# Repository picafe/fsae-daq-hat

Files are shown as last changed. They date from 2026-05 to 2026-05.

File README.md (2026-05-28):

# FSAE Pi HAT
## What this project is

This project is a revision 2.5 of the Raspberry Pi DAQ (data acquisition) HAT for Western Formula Racing FSAE. It consolidates the features still needed from the failed rev 2 boards into a single HAT: a 24 V → 5 V buck converter to power the Pi, input protection on the car rail, CAN transceiver + controller, static PoE injection control, and RTC with coin cell for the Pi 4B.

## Why I made it

A few months ago, I and another WFR team member tested and diagnosed a cause of catastrophic failure of the rev 2 DAQ HAT using voltage injection and a thermal camera. Although rev 3 was planned, and I am still working on it with help from others, the current failed rev 2 PCBs are still being partially used for their features that still function. This aims to be a quick revision that consolidates some of the features, while being cheap to manufacture. When revision 3 is finished, these boards can act as a backup.

The buck converter is one of the essential parts of the hat. Existing modules cut too many corners to be reliable, especially at 3A peak current. Currently, the buck coverter on the Rev 2 board is blown up. 

Rev 2 also included a boost converter to boost 20V USB-C PD to 24 V for injecting PoE for the base station antenna, and for ease of powering during testing. Since this is at a lower current, I decided to use a modified MT3608 boost converter and a PDC004 USB-C PD trigger on a separate PCB for ease of design and cost.

## Pictures

### 3D

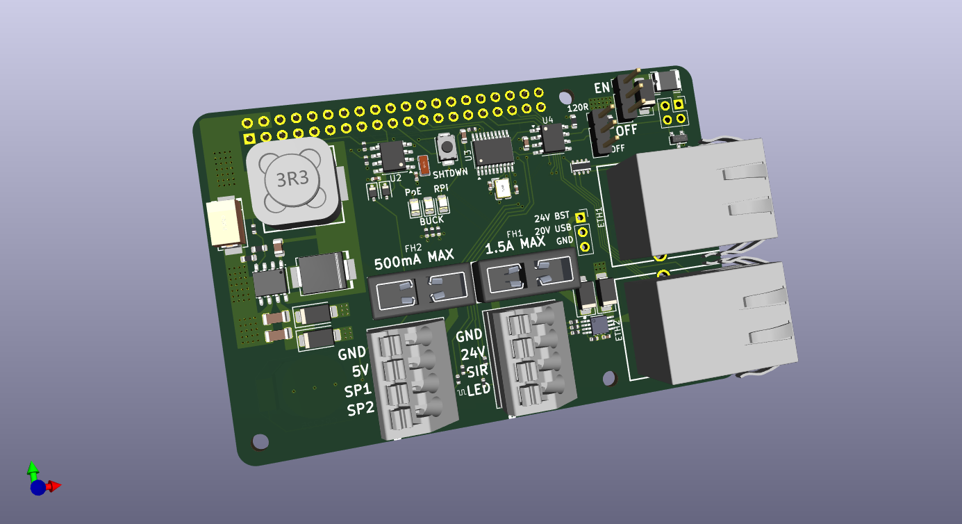
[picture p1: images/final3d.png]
3D view


### Schematic

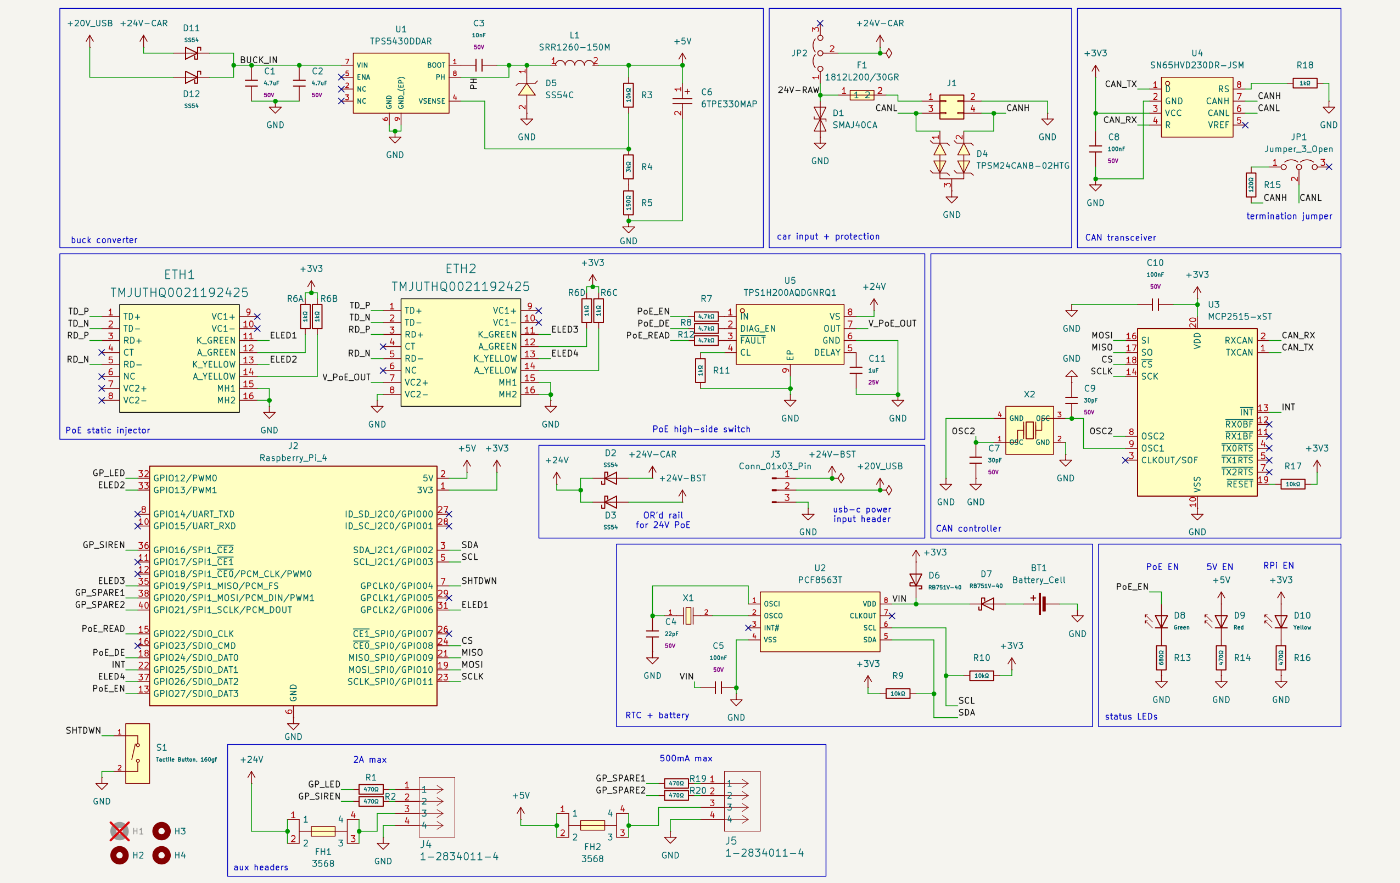
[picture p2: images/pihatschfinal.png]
Final schematic sheet


**[View schematic online (KiCanvas)](https://kicanvas.org/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)**

### PCB (KiCad)

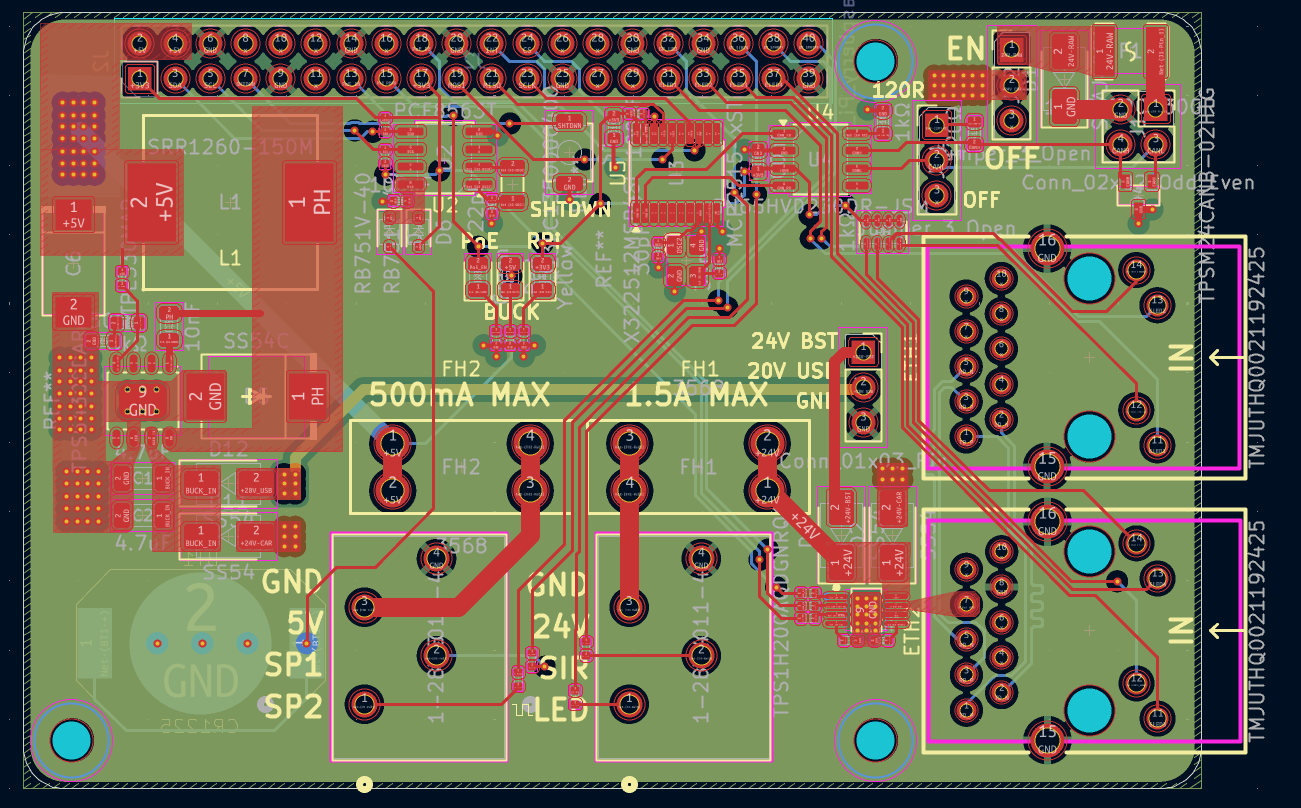
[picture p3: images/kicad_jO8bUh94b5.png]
PCB layout top layer

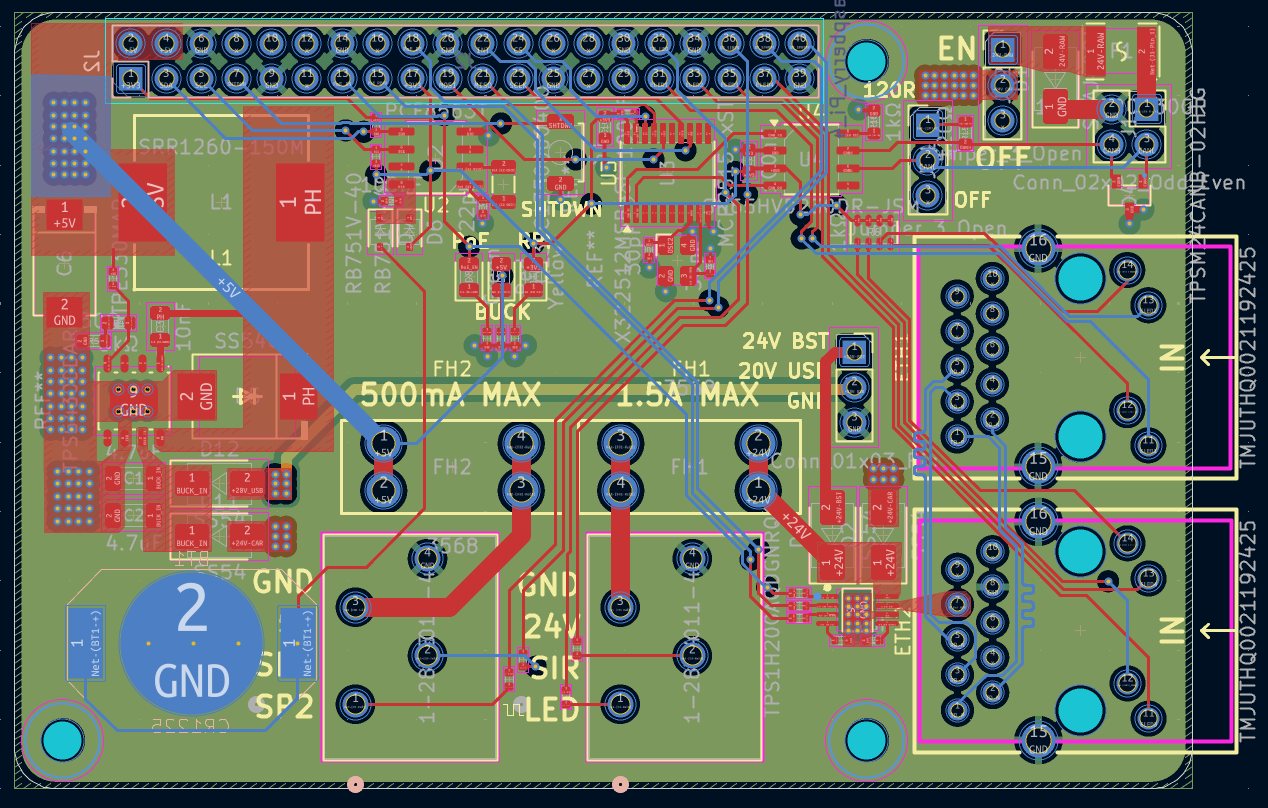
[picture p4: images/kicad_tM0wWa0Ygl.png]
PCB layout bottom layer


**[View PCB online (KiCanvas)](https://kicanvas.org/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)**

### Wiring (off-board)

The 20 V USB-C PD → 24 V boost path is **not** on this HAT. It is implemented on the companion [USB boost/PD module](./fsae-pihat-usbmod/README.md), wired to the **J3** pads on the HAT.

```text
HAT J3 pads (no header installed)
    │  wire
    ▼
Deutsch connector
    │  wire
    ▼
USB-C PD breakout (MT3608 + PDC004)
```
The 2 main power devices source power from different sources using power OR-ing with schottky barrier diodes. 

The buck converter is powered by 24V from the car rail or the 20V USB-C PD (to reduce strain on the boost converter and to keep less ripple on the 5 V rail).
The PoE injector is powered by 24V from the car rail or the 24v boost converter.

A jumper on the **24 V car** input (JP2) can disable the car rail without unplugging the Deutsch connector, to preserve the car battery during bench testing. This MUST be populated to enable the car rail with a high current 0.1" pitch jumper. There is also a CAN termination jumper (JP1) to enable or disable 120Ω termination on the CAN bus.

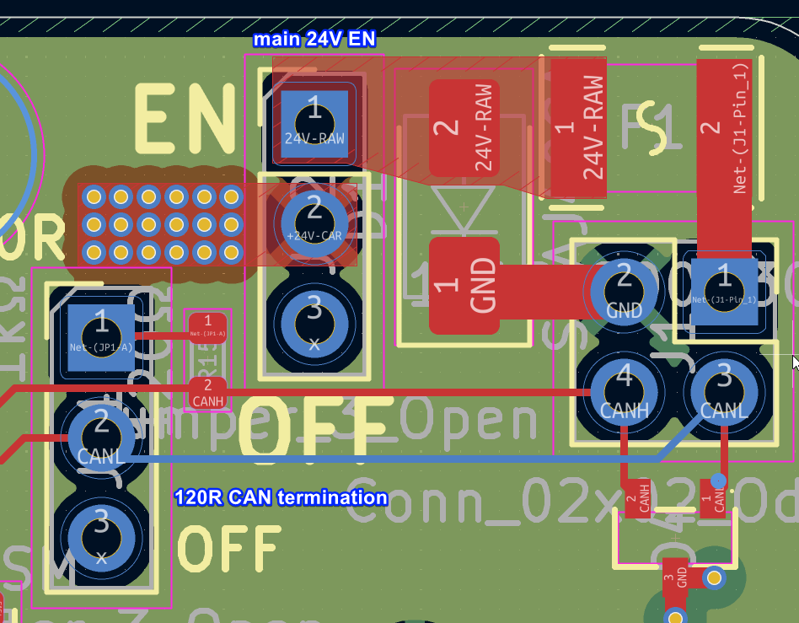
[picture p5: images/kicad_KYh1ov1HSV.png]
Car-rail disable jumper (JP2)


## USB boost / PD module

The MT3608 boost and PDC004 USB-C PD trigger are on a separate PCB. Schematics, layout, images, and BOM for that board are in **[fsae-pihat-usbmod/README.md](./fsae-pihat-usbmod/README.md)**.

## Bill of materials (Pi HAT)

### JLCPCB SMT assembly

| Refs | Qty | Description | LCSC | Unit (USD) | Min | Ext. @ min (USD) |
| --- | ---: | --- | --- | ---: | ---: | ---: |
| C1, C2, C3 | 3 | 4.7 µF ±10% 50 V X7R ceramic, 1206 | [C29823](https://www.lcsc.com/product-detail/C29823.html) | $0.0426 | 10 | $0.43 |
| C10, C9 | 2 | 30 pF ±5% 50 V C0G ceramic, 0402 | [C1570](https://www.lcsc.com/product-detail/C1570.html) | $0.0013 | 100 | $0.13 |
| C11, C12 | 2 | 100 nF ±10% 50 V X7R ceramic, 0603 | [C14663](https://www.lcsc.com/product-detail/C14663.html) | $0.0031 | 100 | $0.31 |
| C4 | 1 | 10 nF ±10% 50 V X7R ceramic, 0805 | [C1710](https://www.lcsc.com/product-detail/C1710.html) | $0.0072 | 50 | $0.36 |
| C5 | 1 | 22 pF ±5% 50 V C0G ceramic, 0402 | [C1555](https://www.lcsc.com/product-detail/C1555.html) | $0.0014 | 100 | $0.14 |
| C6 | 1 | 330 µF ±20% 6.3 V tantalum, 7.3×4.3 mm SMD (6TPE330MAP) | [C79112](https://www.lcsc.com/product-detail/C79112.html) | $0.6851 | 1 | $0.69 |
| C7 | 1 | 100 nF ±10% 50 V X7R ceramic, 0402 | [C307331](https://www.lcsc.com/product-detail/C307331.html) | $0.0047 | 100 | $0.47 |
| C8 | 1 | 1 µF ±10% 25 V X5R ceramic, 0402 | [C52923](https://www.lcsc.com/product-detail/C52923.html) | $0.0040 | 100 | $0.40 |
| D1, D2, D4, D5 | 4 | 40 V 5 A Schottky, SMA (SS54) | [C7420369](https://www.lcsc.com/product-detail/C7420369.html) | $0.0448 | 10 | $0.45 |
| D10 | 1 | Emerald green 525 nm LED, 2.6–3.1 V, 0805 | [C2297](https://www.lcsc.com/product-detail/C2297.html) | $0.0163 | 50 | $0.82 |
| D11 | 1 | Red 630 nm LED, 1.6–2.6 V, 0805 | [C84256](https://www.lcsc.com/product-detail/C84256.html) | $0.0133 | 50 | $0.67 |
| D12 | 1 | Yellow 596 nm LED, 1.8–2.4 V, 0805 | [C2296](https://www.lcsc.com/product-detail/C2296.html) | $0.0122 | 50 | $0.61 |
| D3 | 1 | 40 V 5 A Schottky, SMC (SS54C) | [C18199188](https://www.lcsc.com/product-detail/C18199188.html) | $0.0737 | 10 | $0.74 |
| D6 | 1 | 64.5 V clamp TVS, 6.2 A Ipp, DO-214AC/SMA (SMAJ40CA) | — | — | — | — |
| D7, D9 | 2 | 40 V 30 mA Schottky, SOD-323 (RB751V-40) | [C7502691](https://www.lcsc.com/product-detail/C7502691.html) | $0.0149 | 50 | $0.75 |
| D8 | 1 | 50 V CAN TVS clamp, 5.5 A Ipp, SOT-23 (TPSM24CANB-02HTG) | [C970029](https://www.lcsc.com/product-detail/C970029.html) | $0.0495 | 10 | $0.50 |
| F1 | 1 | Polymeric PTC resettable fuse, 30 V 2 A, 1812 (1812L200/30GR) | [C18198342](https://www.lcsc.com/product-detail/C18198342.html) | $0.0812 | 5 | $0.41 |
| L1 | 1 | 15 µH ±20% shielded inductor, 5 A, 12.5×12.5 mm (SRR1260-150M) | [C2041333](https://www.lcsc.com/product-detail/C2041333.html) | $1.3721 | 1 | $1.37 |
| R1 | 1 | 1 kΩ ±5% resistor network, 0603×4 | [C20197](https://www.lcsc.com/product-detail/C20197.html) | $0.0059 | 50 | $0.30 |
| R10, R11, R12 | 3 | 4.7 kΩ ±1% thick-film, 0402 | [C25900](https://www.lcsc.com/product-detail/C25900.html) | $0.0010 | 100 | $0.10 |
| R13, R14, R19, R21, R4 | 5 | 10 kΩ ±1% thick-film, 0402 | [C25744](https://www.lcsc.com/product-detail/C25744.html) | $0.0013 | 100 | $0.13 |
| R15 | 1 | 680 Ω ±1% thick-film, 0402 | [C25130](https://www.lcsc.com/product-detail/C25130.html) | $0.0011 | 100 | $0.11 |
| R16, R18, R2, R3, R7, R8 | 6 | 470 Ω ±1% thick-film, 0402 | [C25117](https://www.lcsc.com/product-detail/C25117.html) | $0.0008 | 100 | $0.08 |
| R17 | 1 | 120 Ω ±1% thick-film, 0603 (CAN termination) | [C22787](https://www.lcsc.com/product-detail/C22787.html) | $0.0014 | 100 | $0.14 |
| R20 | 1 | 1 kΩ ±1% thick-film, 0603 | [C21190](https://www.lcsc.com/product-detail/C21190.html) | $0.0016 | 100 | $0.16 |
| R5 | 1 | 3 kΩ ±1% thick-film, 0603 | [C4211](https://www.lcsc.com/product-detail/C4211.html) | $0.0014 | 100 | $0.14 |
| R6 | 1 | 150 Ω ±1% thick-film, 0603 | [C22808](https://www.lcsc.com/product-detail/C22808.html) | $0.0018 | 100 | $0.18 |
| R9 | 1 | 1 kΩ ±1% thick-film, 0402 | [C11702](https://www.lcsc.com/product-detail/C11702.html) | $0.0011 | 100 | $0.11 |
| S1 | 1 | Tactile switch SPST, 160 gf, 4×3 mm SMD (TS-1088) | [C720477](https://www.lcsc.com/product-detail/C720477.html) | $0.0538 | 10 | $0.54 |
| U1 | 1 | TPS5430 buck regulator, 3 A, 5.5–36 V in, SOIC-8-EP | [C9864](https://www.lcsc.com/product-detail/C9864.html) | $0.7486 | 1 | $0.75 |
| U2 | 1 | TPS1H200A 2.5 A high-side switch (PoE injector), EMSOP-8-EP | [C2653785](https://www.lcsc.com/product-detail/C2653785.html) | $0.7476 | 1 | $0.75 |
| U3 | 1 | PCF8563T I²C real-time clock, SO-8 | [C7440](https://www.lcsc.com/product-detail/C7440.html) | $0.5834 | 1 | $0.58 |
| U4 | 1 | SN65HVD230 3.3 V CAN transceiver, 5 Mbps, SOP-8 | [C46596299](https://www.lcsc.com/product-detail/C46596299.html) | $0.4853 | 1 | $0.49 |
| U5 | 1 | MCP2515 1 Mbps CAN controller, TSSOP-20 | — | — | — | — |
| X1 | 1 | 32.768 kHz crystal ±20 ppm, 12.5 pF, SMD3215-2P | [C32346](https://www.lcsc.com/product-detail/C32346.html) | $0.1804 | 5 | $0.90 |
| X2 | 1 | 12 MHz crystal ±10 ppm, 20 pF, SMD3225-4P | [C9002](https://www.lcsc.com/product-detail/C9002.html) | $0.0744 | 10 | $0.74 |
| | | **LCSC subtotal @ MOQ** | | | | **$15.45 + 2 unlinked line items** |

### DigiKey (hand assembly)

| Refs | Qty | Description | DigiKey | Unit (CAD) | Ext. (CAD) |
| --- | ---: | --- | --- | ---: | ---: |
| J2 | 1 | 2×20 extended female GPIO header | [1568-16763-ND](https://www.digikey.ca/en/products/detail/sparkfun-electronics/16763/12686348) | $4.70 | $4.70 |
| J4, J5 | 2 | 4-pos 3.5 mm top-entry terminal block | [A123850-ND](https://www.digikey.ca/en/products/detail/te-connectivity-amp-connectors/1-2834011-4/5872966) | $1.57 | $3.14 |
| ETH1, ETH2 | 2 | RJ45 magjack 10/100 + PoE (Taoglas) | [931-TMJUTHQ0021192425-ND](https://www.digikey.ca/en/products/detail/taoglas-limited/TMJUTHQ0021192425/21777733) | $9.04 | $18.08 |
| FH1, FH2 | 2 | Blade fuse holder 30 A 500 V PCB | [36-3568-ND](https://www.digikey.ca/en/products/detail/keystone-electronics/3568/2137306) | $1.69 | $3.38 |
| BT1 | 1 | CR1225 coin-cell holder, 12 mm SMD | [BAT-HLD-012-SMTCT-ND](https://www.digikey.ca/en/products/detail/te-connectivity-linx/BAT-HLD-012-SMT-TR/5361776) | $0.75 | $0.75 |
| — | 1 | CR1225 3 V lithium cell (fits BT1) | *(Amazon, etc.)* | — | — |
| JP1, JP2 | 2 | 1×3 2.54 mm vertical pin header (solder to `JP1` / `JP2` footprints) | *(any 1×3 0.1″ 3A rated header)* | — | — |
| JP1 | 1 | CAN 120 Ω termination shunt | [S9341-ND](https://www.digikey.ca/en/products/detail/sullins-connector-solutions/NPC02SXON-RC/2618266) | $0.075 | $0.08 |
| JP2 | 1 | 24 V car-rail enable shunt | [S9341-ND](https://www.digikey.ca/en/products/detail/sullins-connector-solutions/NPC02SXON-RC/2618266) | $0.075 | $0.08 |
| | | **DigiKey subtotal (per board)** | | | **$30.20** |

**Not populated (DNP):**

| Refs | Footprint on PCB | Notes |
| --- | --- | --- |
| J1 | 2×2 pin socket | Do not install; car input harness wires solder to |
| J3 | 1×3 pin header | Do not install; boost/PD harness wires solder to |

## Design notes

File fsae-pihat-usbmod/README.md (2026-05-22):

# FSAE Pi HAT USB Boost / PD Module

## What this project is

This PCB is the external **20 V USB-C PD → 24 V boost** module used with the [main Pi HAT](../README.md). It pairs a **PDC004 V2** USB-C PD trigger (fixed 20 V) with an **MT3608** boost module to generate 24 V for PoE injection on the base station antenna and for convenient bench power during testing. This is a companion PCB to the main Pi HAT.

## Why I made it

Since the current here would be pretty low, I decided to use a MT3608 and PDC004 PD module (I already have one, and the design seems pretty good; really big power plane on bottom) on a separate PCB instead of putting a boost converter on the HAT.

The MT3608 module also should be able to handle the current required (2 A) for the 24 V PoE injection, which should be around 1 A peak. The IC itself is pretty capable; there often just is not a great component selection or insufficient decoupling/filtering. I remembered [this GreatScott video](https://www.youtube.com/watch?v=6bicunweBAQ) where he added a 2.2 µF 1210 capacitor to the output of the MT3608 to improve output ripple, so I added **C1 (2.2 µF)**.

## Pictures

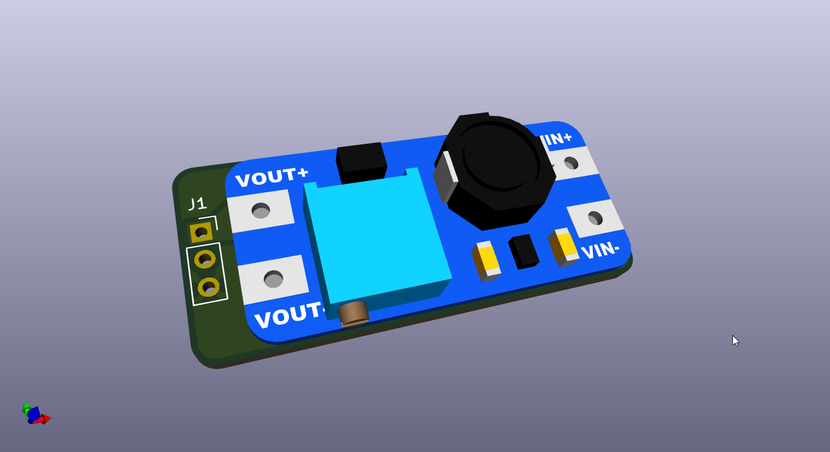
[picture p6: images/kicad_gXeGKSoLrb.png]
3D view top (MT3608)


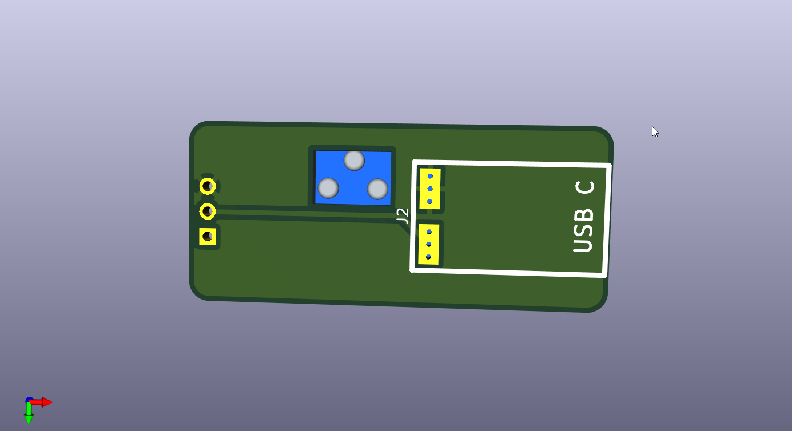
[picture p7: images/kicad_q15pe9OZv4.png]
3D view bottom (PDC004)


### Schematic

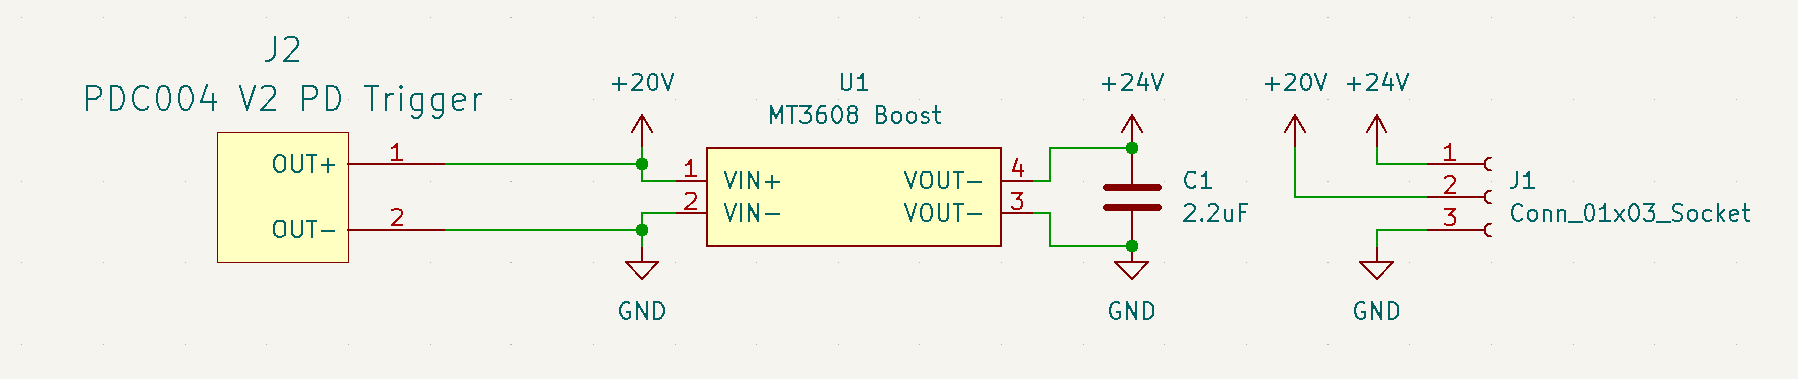
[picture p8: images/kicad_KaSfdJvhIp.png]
Schematic sheet


**[View schematic online (KiCanvas)](https://kicanvas.org/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)**

### PCB

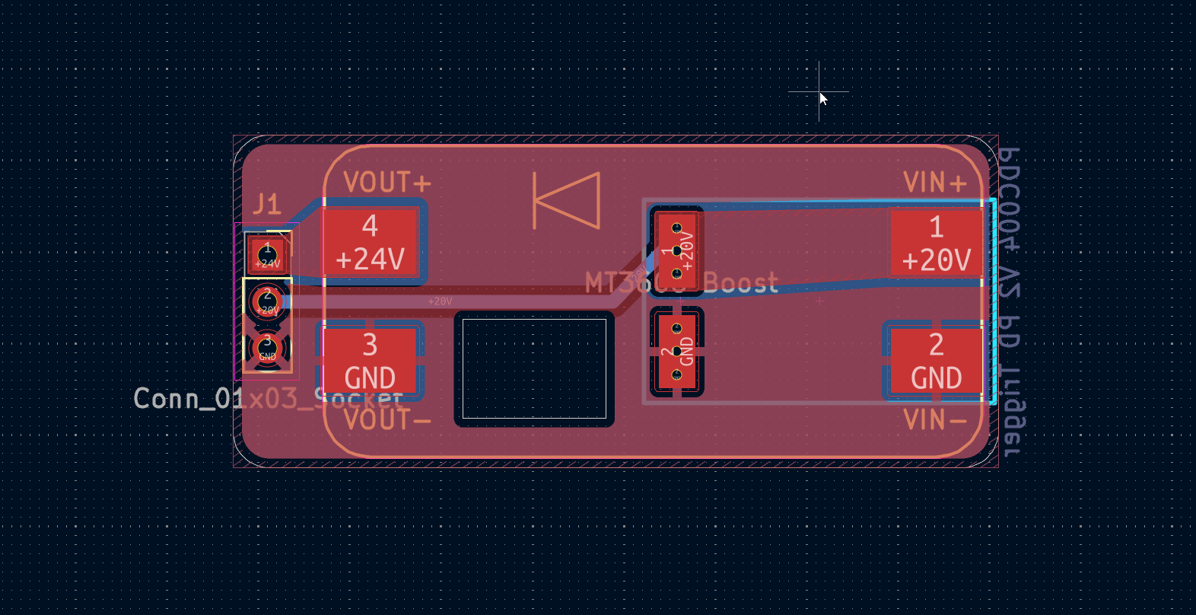
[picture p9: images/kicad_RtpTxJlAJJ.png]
PCB layout top)


**[View PCB online (KiCanvas)](https://kicanvas.org/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)**

### Wiring (off-board)

Connect to the main HAT **J3** and a USB-C PD supply:

```text
USB-C PD supply (20 V negotiated)
    │
    ▼
PDC004 module (J2, bottom of this PCB) ──► +20 V rail
    │
    ▼
MT3608 boost (U1, top of this PCB) ──► +24 V
    │
    ▼
3-pin header J1 ──► wires ──► Deutsch connectors ──► main HAT J3
```

For the PCB, the PD module is surface mount on the bottom and the MT3608 on the top, since both have large pads on both sides with vias.

## Bill of materials

| Designator | Footprint / package | Qty | Value | Notes |
| --- | --- | ---: | --- | --- |
| J1 | PinSocket_1x03_P2.54mm_Vertical | 1 | Conn_01x03_Socket | To main HAT |
| J2 | PDC004 Module | 1 | PDC004 PD Trigger | Fixed 20 V USB-C PD; AliExpress module |
| U1 | MT3608 Module | 1 | MT3608 Boost | AliExpress / generic boost module |
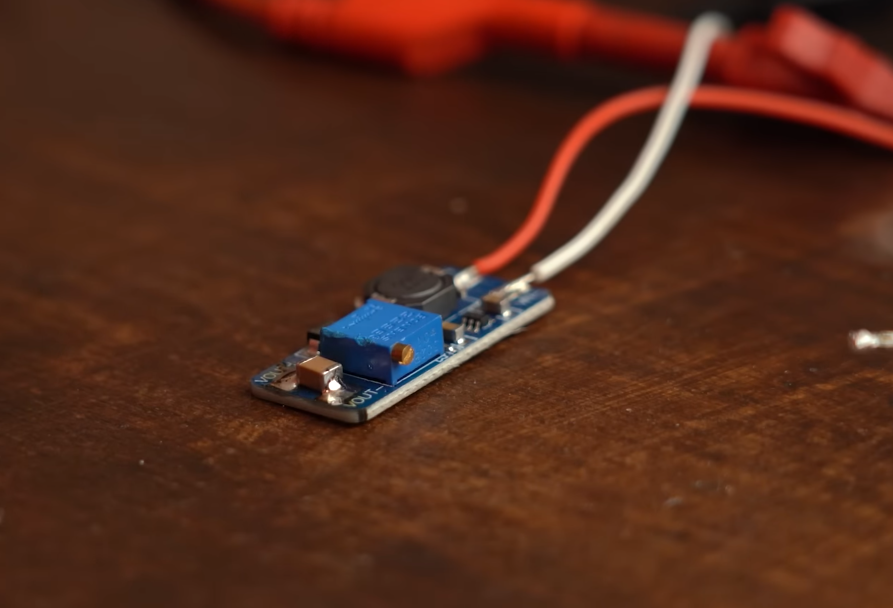
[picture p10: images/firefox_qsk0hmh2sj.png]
soldering example - GreatScott
| C1 | C_1210 (hand solder on module) | 1 | [2.2 µF, 50V X7R 1210 CL32B225KBJNNNE](https://www.digikey.ca/en/products/detail/samsung-electro-mechanics/CL32B225KBJNNNE/3888542) | Output stability cap; solder on MT3608 output  |

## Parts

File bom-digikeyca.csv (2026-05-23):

Index | Quantity | Part Number | Manufacturer Part Number | Description | Customer Reference | Available | Backorder | Unit Price | Extended Price CAD
1 | 1 | 1568-16763-ND | 16763 | EXTENDED GPIO FEMALE HEADER - 2X |  | 1 | 0 | 4.70000 | 4.70
2 | 2 | A123850-ND | 1-2834011-4 | TERM BLK 4P TOP ENTRY 3.5MM PCB |  | 2 | 0 | 1.57000 | 3.14
3 | 10 | 1276-2884-1-ND | CL32B225KBJNNNE | CAP CER 2.2UF 50V X7R 1210 |  | 10 | 0 | 0.29300 | 2.93
4 | 1 | BAT-HLD-012-SMTCT-ND | BAT-HLD-012-SMT-TR | BATTERY RETAINER COIN 12MM SMD |  | 1 | 0 | 0.75000 | 0.75
5 | 2 | 931-TMJUTHQ0021192425-ND | TMJUTHQ0021192425 | CONN JACK 1PORT PCB |  | 2 | 0 | 9.04000 | 18.08
6 | 2 | 36-3568-ND | 3568 | FUSE HOLDER BLADE 500V 30A PCB |  | 2 | 0 | 1.69000 | 3.38
7 | 10 | S9341-ND | NPC02SXON-RC | CONN JUMPER SHORTING .100" GOLD |  | 10 | 0 | 0.07500 | 0.75

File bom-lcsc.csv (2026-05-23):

Mrf# | Mfr. | Order Qty. | Unit Price(USD) | Ext.Price(USD) | LCSC# | Package | Min | Mult | SPQ | Availability | Stock Status | Customer Notes | Description | Product Link
1206B475K500NT | FH | 10 | 0.0426 | 0.43 | C29823 | 1206 | 10 | 10 | 2000 | 1077010 | In Stock |  | 4.7uF ±10% 50V Ceramic Capacitor X7R 1206 | https://www.lcsc.com/product-detail/C29823.html
CC0603KRX7R9BB104 | YAGEO | 100 | 0.0031 | 0.31 | C14663 | 0603 | 100 | 100 | 4000 | 4000 | In Stock |  | 100nF ±10% 50V Ceramic Capacitor X7R 0603 | https://www.lcsc.com/product-detail/C14663.html
CL05A105KA5NQNC | Samsung Electro-Mechanics | 100 | 0.0040 | 0.40 | C52923 | 0402 | 100 | 100 | 10000 | 5280800 | In Stock |  | 1uF ±10% 25V Ceramic Capacitor X5R 0402 | https://www.lcsc.com/product-detail/C52923.html
CL21B103KBANNNC | Samsung Electro-Mechanics | 50 | 0.0072 | 0.36 | C1710 | 0805 | 50 | 50 | 4000 | 2204650 | In Stock |  | 10nF ±10% 50V Ceramic Capacitor X7R 0805 | https://www.lcsc.com/product-detail/C1710.html
0402CG220J500NT | FH | 100 | 0.0014 | 0.14 | C1555 | 0402 | 100 | 100 | 10000 | 1105400 | In Stock |  | 22pF ±5% 50V Ceramic Capacitor C0G 0402 | https://www.lcsc.com/product-detail/C1555.html
CL05B104KB54PNC | Samsung Electro-Mechanics | 100 | 0.0047 | 0.47 | C307331 | 0402 | 100 | 100 | 10000 | 9088600 | In Stock |  | 100nF ±10% 50V Ceramic Capacitor X7R 0402 | https://www.lcsc.com/product-detail/C307331.html
6TPE330MAP | PANASONIC | 1 | 0.6851 | 0.69 | C79112 | SMD,7.3x4.3mm | 1 | 1 | 3000 | 28646 | In Stock |  | 330uF ±20% 6.3V Tantalum Capacitors 25m?@100kHz SMD,7.3x4.3mm | https://www.lcsc.com/product-detail/C79112.html
0402CG300J500NT | FH | 100 | 0.0013 | 0.13 | C1570 | 0402 | 100 | 100 | 10000 | 144400 | In Stock |  | 30pF ±5% 50V Ceramic Capacitor C0G 0402 | https://www.lcsc.com/product-detail/C1570.html
SMAJ40CA | R+O | 20 | 0.0335 | 0.67 | C19077552 | DO-214AC(SMA) | 20 | 20 | 5000 | 155060 | In Stock |  | 64.5VC Clamp 6.2A@10/1000us Ipp TVS DIODE DO-214AC(SMA) | https://www.lcsc.com/product-detail/C19077552.html
KT-0805Y | Hubei KENTO Elec | 50 | 0.0122 | 0.61 | C2296 | 0805 | 50 | 50 | 3000 | 68700 | In Stock |  | Yellow 596nm LED Indication - Discrete 1.8V~2.4V 0805 | https://www.lcsc.com/product-detail/C2296.html
SS54 | R+O | 10 | 0.0448 | 0.45 | C7420369 | SMA(DO-214AC) | 10 | 10 | 5000 | 1387830 | In Stock |  | Diode Independent 40V 5A Surface Mount SMA(DO-214AC) | https://www.lcsc.com/product-detail/C7420369.html
TPSM24CANB-02HTG | TECH PUBLIC | 10 | 0.0495 | 0.50 | C970029 | SOT-23 | 10 | 10 | 3000 | 24140 | In Stock |  | 50VC Clamp 5.5A@8/20us Ipp SOT-23 | https://www.lcsc.com/product-detail/C970029.html
SS54C | R+O | 10 | 0.0737 | 0.74 | C18199188 | SMC | 10 | 10 | 3000 | 0 | Backordered |  | Diode Independent 40V 5A Surface Mount SMC | https://www.lcsc.com/product-detail/C18199188.html
RB751V-40 | R+O | 50 | 0.0149 | 0.75 | C7502691 | SOD-323 | 50 | 50 | 3000 | 510250 | In Stock |  | Diode Independent 40V 0.03A Surface Mount SOD-323 | https://www.lcsc.com/product-detail/C7502691.html
KT-0805G | Hubei KENTO Elec | 50 | 0.0163 | 0.82 | C2297 | 0805 | 50 | 50 | 3000 | 759200 | In Stock |  | Emerald Green 525nm LED Indication - Discrete 2.6V~3.1V 0805 | https://www.lcsc.com/product-detail/C2297.html
NCD0805R1 | NATIONSTAR | 50 | 0.0133 | 0.67 | C84256 | 0805 | 50 | 50 | 3000 | 2975000 | In Stock |  | Red 630nm LED Indication - Discrete 1.6V~2.6V 0805 | https://www.lcsc.com/product-detail/C84256.html
1812L200/30GR | LUTE | 5 | 0.0812 | 0.41 | C18198342 | 1812 | 5 | 5 | 1500 | 122970 | In Stock |  | Polymeric PTC Resettable Fuse 30V 2A Surface Mount 1812 | https://www.lcsc.com/product-detail/C18198342.html
SRR1260-150M | BOURNS | 1 | 1.3721 | 1.37 | C2041333 | SMD,12.5x12.5mm | 1 | 1 | 600 | 484 | In Stock |  | 5A 15uH ±20% 4.6A 27m? Magnetic Shielded Inductor SMD,12.5x12.5mm Fixed Inductors RoHS | https://www.lcsc.com/product-detail/C2041333.html
0402WGF4700TCE | UNI-ROYAL | 100 | 0.0008 | 0.08 | C25117 | 0402 | 100 | 100 | 10000 | 1654200 | In Stock |  | 470? ±1% 62.5mW 0402 Thick Film Resistor | https://www.lcsc.com/product-detail/C25117.html
0402WGF1002TCE | UNI-ROYAL | 100 | 0.0013 | 0.13 | C25744 | 0402 | 100 | 100 | 10000 | 0 | Backordered |  | 10k? ±1% 62.5mW 0402 Thick Film Resistor | https://www.lcsc.com/product-detail/C25744.html
0402WGF1001TCE | UNI-ROYAL | 100 | 0.0011 | 0.11 | C11702 | 0402 | 100 | 100 | 10000 | 0 | Backordered |  | 1k? ±1% 62.5mW 0402 Thick Film Resistor | https://www.lcsc.com/product-detail/C11702.html
0402WGF4701TCE | UNI-ROYAL | 100 | 0.0010 | 0.10 | C25900 | 0402 | 100 | 100 | 10000 | 0 | Backordered |  | 4.7k? ±1% 62.5mW 0402 Thick Film Resistor | https://www.lcsc.com/product-detail/C25900.html
0402WGF6800TCE | UNI-ROYAL | 100 | 0.0011 | 0.11 | C25130 | 0402 | 100 | 100 | 10000 | 0 | Backordered |  | 680? ±1% 62.5mW 0402 Thick Film Resistor | https://www.lcsc.com/product-detail/C25130.html
0603WAF1200T5E | UNI-ROYAL | 100 | 0.0014 | 0.14 | C22787 | 0603 | 100 | 100 | 5000 | 185100 | In Stock |  | 120? ±1% 100mW 0603 Thick Film Resistor | https://www.lcsc.com/product-detail/C22787.html
0603WAF1001T5E | UNI-ROYAL | 100 | 0.0016 | 0.16 | C21190 | 0603 | 100 | 100 | 5000 | 0 | Backordered |  | 1k? ±1% 100mW 0603 Thick Film Resistor | https://www.lcsc.com/product-detail/C21190.html
0603WAF3001T5E | UNI-ROYAL | 100 | 0.0014 | 0.14 | C4211 | 0603 | 100 | 100 | 5000 | 1931400 | In Stock |  | 3k? ±1% 100mW 0603 Thick Film Resistor | https://www.lcsc.com/product-detail/C4211.html
0603WAF1500T5E | UNI-ROYAL | 100 | 0.0018 | 0.18 | C22808 | 0603 | 100 | 100 | 5000 | 68100 | In Stock |  | 150? ±1% 100mW 0603 Thick Film Resistor | https://www.lcsc.com/product-detail/C22808.html
4D03WGJ0102T5E | UNI-ROYAL | 50 | 0.0059 | 0.30 | C20197 | 0603x4 | 50 | 50 | 5000 | 0 | Backordered |  | 1k? ±5% 62.5mW 0603x4 Resistor Networks, Arrays | https://www.lcsc.com/product-detail/C20197.html
TS-1088-AR02016 | XUNPU | 10 | 0.0538 | 0.54 | C720477 | SMD,4x3mm | 10 | 10 | 4000 | 582260 | In Stock |  | Tactile Switch SPST 160gf 2mm SMD (SMT) Tab 4mm x 3mm Surface Mount | https://www.lcsc.com/product-detail/C720477.html
TPS5430DDAR | TI | 1 | 0.7486 | 0.75 | C9864 | SOIC-8-EP | 1 | 1 | 2500 | 50000 | In Stock |  | 500kHz Step-down type Adjustable 1.221V~32.04V 3A 5.5V~36V SOIC-8-EP Voltage Regulators - DC DC Switching Regulators RoHS | https://www.lcsc.com/product-detail/C9864.html
PCF8563T/5,518 | NXP | 1 | 0.5834 | 0.58 | C7440 | SO-8 | 1 | 1 | 2500 | 66835 | In Stock |  | External Yes SO-8 Real Time Clocks RoHS | https://www.lcsc.com/product-detail/C7440.html
MCP2515T-I/ST | MICROCHIP | 1 | 1.2094 | 1.21 | C185941 | TSSOP-20 | 1 | 1 | 2500 | 39302 | In Stock |  | 1Mbps CAN Controller TSSOP-20 Interface Controllers RoHS | https://www.lcsc.com/product-detail/C185941.html
SN65HVD230DR-JSM | JSMSEMI | 1 | 0.4853 | 0.49 | C46596299 | SOP-8 | 1 | 1 | 2500 | 17604 | In Stock |  | 3.3V CAN Transceiver 5Mbps SOP-8 Drivers, Receivers, Transceivers RoHS | https://www.lcsc.com/product-detail/C46596299.html
TPS1H200AQDGNRQ1 | TI | 1 | 0.7476 | 0.75 | C2653785 | EMSOP-8-EP | 1 | 1 | 2500 | 8527 | In Stock |  | High Side Switch 1 Channel 2.5A EMSOP-8-EP | https://www.lcsc.com/product-detail/C2653785.html
Q13FC13500004 | EPSON | 5 | 0.1804 | 0.90 | C32346 | SMD3215-2P | 5 | 5 | 3000 | 274615 | In Stock |  | Crystal 32.768kHz ±20ppm 12.5pF 70k? SMD3215-2P | https://www.lcsc.com/product-detail/C32346.html
X322512MSB4SI | YXC Crystal Oscillators | 10 | 0.0744 | 0.74 | C9002 | SMD3225-4P | 10 | 10 | 3000 | 343650 | In Stock |  | Crystal 12MHz ±10ppm 20pF SMD3225-4P | https://www.lcsc.com/product-detail/C9002.html

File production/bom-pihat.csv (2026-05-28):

Designator | Footprint | Quantity | Value | LCSC Part #
BT1 | BAT-HLD-012-SMT-TR | 1 | Battery_Cell
C1, C2, C3 | C_1206 | 3 | 4.7uF | C29823
C10, C9 | C_0402 | 2 | 30pF | C1570
C11, C12 | C_0603 | 2 | 100nF | C14663
C4 | C_0805 | 1 | 10nF | C1710
C5 | C_0402 | 1 | 22pF | C1555
C6 | CAP-SMD_L7.3-W4.3-R-RD | 1 | 6TPE330MAP | C79112
C7 | C_0402 | 1 | 100nF | C307331
C8 | C_0402 | 1 | 1uF | C52923
D1, D2, D4, D5 | D_SMA | 4 | SS54 | C7420369
D10 | D_0805 | 1 | Green | C2297
D11 | D_0805 | 1 | Red | C84256
D12 | D_0805 | 1 | Yellow | C2296
D3 | SMC_L6.9-W5.9-LS7.9-RD | 1 | SS54C | C18199188
D6 | D_SMA | 1 | SMAJ40CA
D7, D9 | D_SOD-323 | 2 | RB751V-40 | C7502691
D8 | SOT-23-3_L2.9-W1.3-P1.90-LS2.4-BR | 1 | TPSM24CANB-02HTG | C970029
ETH1, ETH2 | TMJUTHQ0021192425 | 2 | TMJUTHQ0021192425
F1 | F1812 | 1 | 1812L200/30GR | C18198342
FH1, FH2 | FUSE-SMD_4P-L16.0-W6.7-P3.40 | 2 | 3568 | C5249699
J1 | PinSocket_2x20_P2.54mm_Vertical | 1 | Raspberry_Pi_4
J2, J3 | CONN_1-2834011-4_TEC | 2 | 1-2834011-4
JP1, JP2 | PinHeader_1x03_P2.54mm_Vertical | 2 | Jumper_3_Open
L1 | IND-SMD_L12.5-W12.5_GSDRK127P | 1 | SRR1260-150M | C2041333
R1 | R_0603x4 | 1 | 1kΩ | C20197
R10, R11, R12 | R_0402 | 3 | 4.7kΩ | C25900
R13, R14, R19, R21, R4 | R_0402 | 5 | 10kΩ | C25744
R15 | R_0402 | 1 | 680Ω | C25130
R16, R18, R2, R3, R7, R8 | R_0402 | 6 | 470Ω | C25117
R17 | R_0603 | 1 | 120Ω | C22787
R20 | R_0603 | 1 | 1kΩ | C21190
R5 | R_0603 | 1 | 3kΩ | C4211
R6 | R_0603 | 1 | 150Ω | C22808
R9 | R_0402 | 1 | 1kΩ | C11702
S1 | SW_SPST_TS-1088-xR020 | 1 | Tactile Button, 160gf | C720477
U1 | ESOP-8_L4.9-W3.9-P1.27-LS6.0-TL-EP | 1 | TPS5430DDAR | C9864
U2 | EMSOP-8_L3.0-W3.0-P0.65-LS4.9-BL-EP-A | 1 | TPS1H200AQDGNRQ1 | C2653785
U3 | SOIC-8_3.9x4.9mm_P1.27mm | 1 | PCF8563T | C7440
U4 | SOP-8_3.9x4.9mm_P1.27mm | 1 | SN65HVD230DR-JSM | C46596299
U5 | TSSOP-20_4.4x6.5mm_P0.65mm | 1 | MCP2515-xST
X1 | FC-135R_L3.2-W1.5 | 1 | Q13FC1350000400 | C32346
X2 | CRYSTAL-SMD_4P-L3.2-W2.5-BL | 1 | X322512MSB4SI | C9002

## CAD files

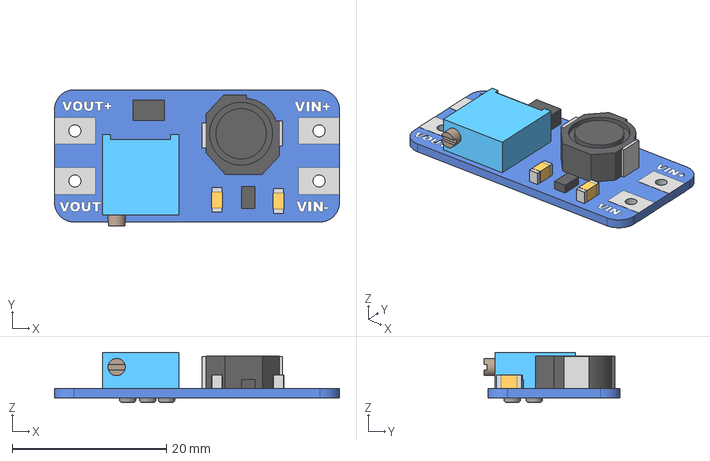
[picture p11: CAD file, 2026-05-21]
fsae-pihat-usbmod/models/MT3608-Module.stp
37.0 x 17.7 x 6.50 mm

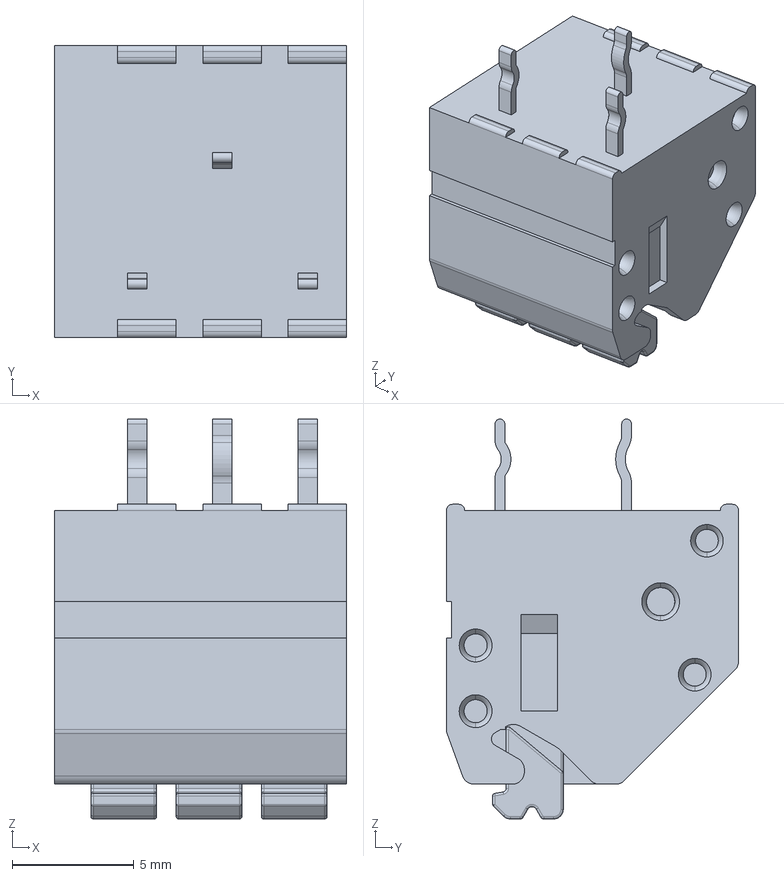
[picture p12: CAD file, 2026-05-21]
fsae-pihat/models/c-1-2834011-3-2-3d.stp
12.0 x 12.0 x 16.4 mm

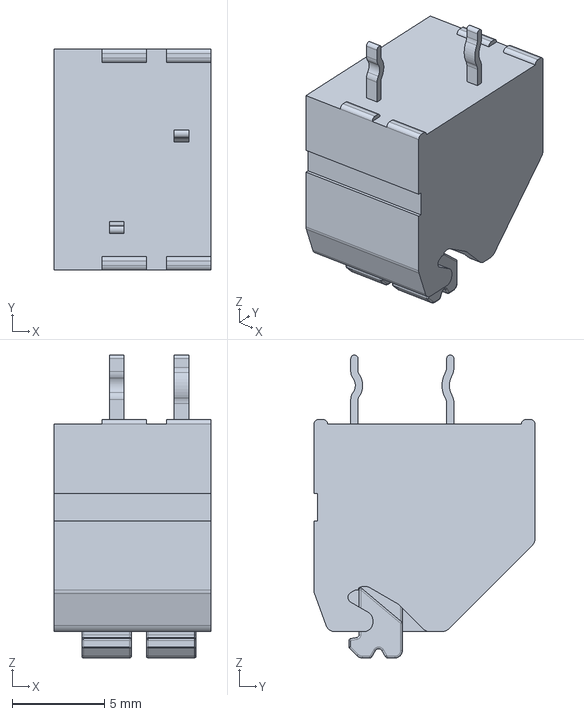
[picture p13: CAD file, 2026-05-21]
fsae-pihat/models/c-1-2834011-2-2-3d.stp
8.50 x 12.0 x 16.4 mm

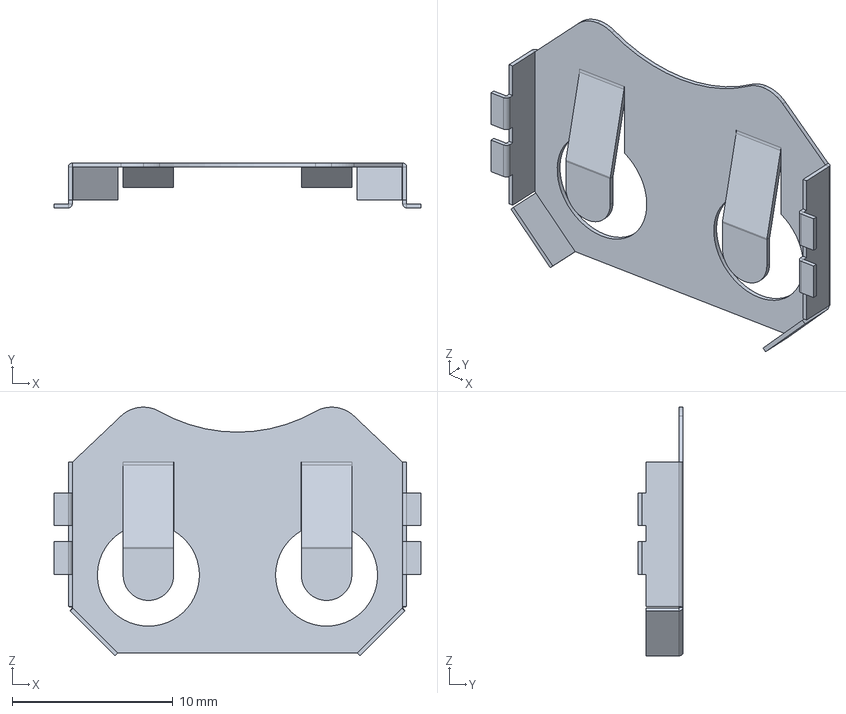
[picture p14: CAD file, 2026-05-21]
fsae-pihat/models/BAT-HLD-002-SMT.stp
22.9 x 2.79 x 15.5 mm

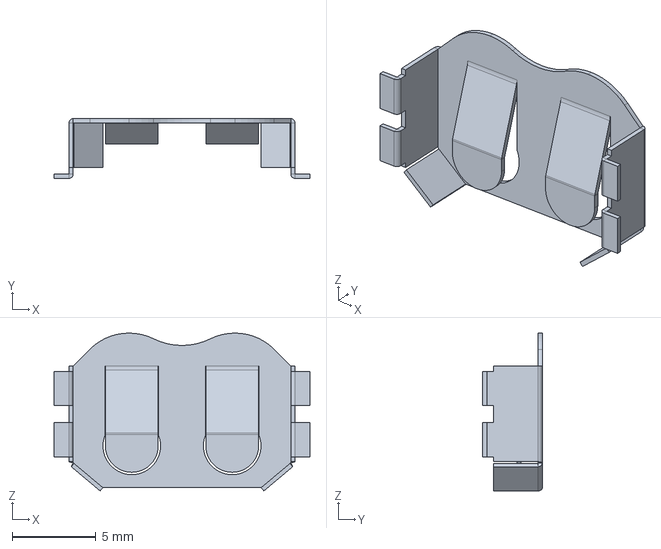
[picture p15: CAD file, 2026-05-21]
fsae-pihat/models/c-bat-hld-012-smt-tr-b-3d.stp
15.2 x 3.56 x 9.40 mm

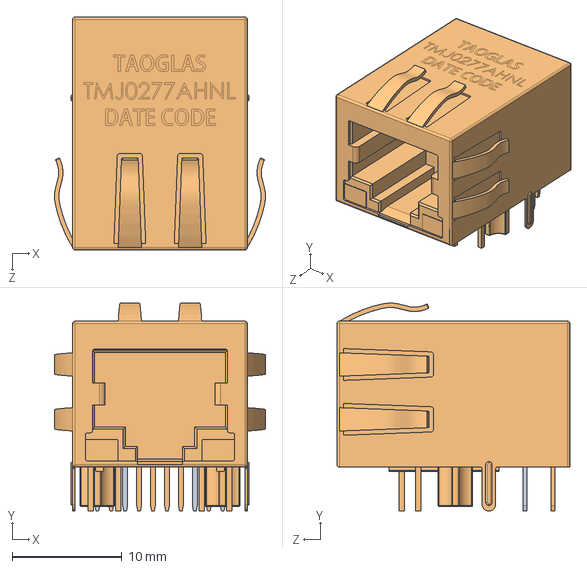
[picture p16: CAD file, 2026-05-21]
fsae-pihat/models/TMJUTHQ0021192425_Web.STEP
19.2 x 18.9 x 21.2 mm

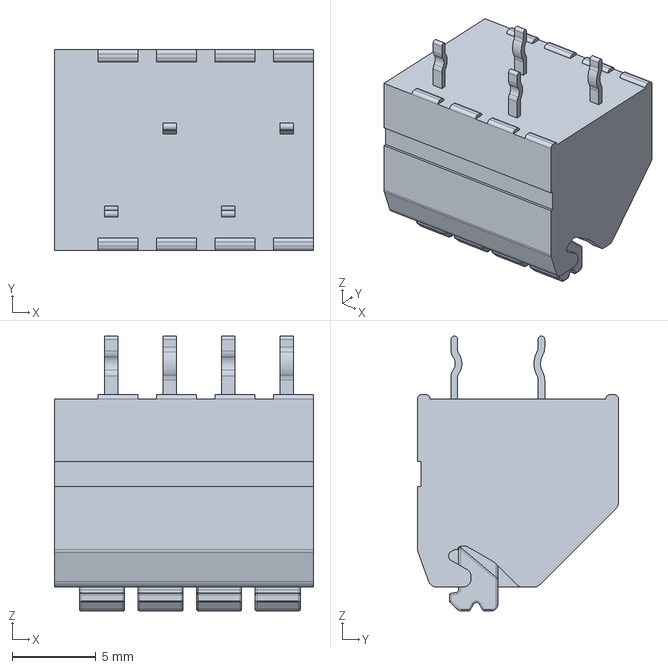
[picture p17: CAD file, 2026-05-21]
fsae-pihat/models/c-1-2834011-4-2-3d.stp
15.5 x 12.0 x 16.4 mm

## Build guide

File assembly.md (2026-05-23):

# Assembly instructions

## 1. USB-C PD / boost module (`fsae-pihat-usbmod`)

This board converts 20 V USB-C PD → 24 V for PoE injection and bench power. It is fully hand-assembled.

### Bill of materials

| Ref | Qty | Part | Notes |
| --- | ---: | --- | --- |
| J2 | 1 | PDC004 V2 USB-C PD trigger | Fixed **20 V** output; AliExpress module (HT50 regulator rev) |
| U1 | 1 | MT3608 boost module | Generic AliExpress / module; ~2 A capable |
| C1 | 1 | 2.2 µF 50 V X7R **1210** ([CL32B225KBJNNNE](https://www.digikey.ca/en/products/detail/samsung-electro-mechanics/CL32B225KBJNNNE/3888542)) | Hand-solder on MT3608 **output**; not placed on PCB |

### Board layout

- **Top:** MT3608 boost (**U1**), output header (**J1**)
- **Bottom:** PDC004 PD module (**J2**), USB-C connector faces down

Both modules use large SMD pads with through-holes, so they are soldered directly to the carrier PCB.

### Assembly order

1. **Solder J2 (PDC004) on the bottom side**
   - Flip the board so the bottom is up.
   - Align the PDC004 module to the **J2** footprint (`USB C` silkscreen marks the connector end).
   - Match **OUT+** (20 V) and **OUT−** (GND) to the labeled pads.
   - Place your soldering iron on the pad, hold for ~6 seconds, and feed solder onto the other side of the pad where your iron isn't.
   - Repeat for the second pad.
   - Turn the board around and look at the vias on the bottom side, underneath where you just soldered.
   - Check to make sure the solder is flowing into the vias and not pooling on the pad. If this is the case, you may need to reflow the pad with flux and/or more heat. 
   - (optional) Add a small piece of kapton tape on the other side of the pcb to conver the vias you just inspected to prevent shorting.

2. **Solder U1 (MT3608) on the top side**
   - Flip to the top side.
   - Align to the **U1** footprint using the silkscreen labels:
     - **VIN+** / **VIN−** input from PDC004 (+20 V / GND)
     - **VOUT+** / **VOUT−** boosted output (+24 V / GND)
   - Solder all four module pads, using the same method as the PD module.

3. **Solder C1 on the MT3608 output**
   - **C1 is not on the PCB**. Solder the 1210 cap directly across the MT3608 module **VOUT+** and **VOUT−** pads (same nodes as the module’s output pins).
   - This follows the approach from [GreatScott’s video](https://www.youtube.com/watch?v=6bicunweBAQ&t=666s) and reduces output ripple/stability issues noted in the design journal.
   - See the video for reference (timestamp linked above).

4. **Adjust boost output to 24 V**
   - Connect a USB-C **PD supply** capable of 20 V to the PDC004.
   - Verify PDC004 output is ~20 V.
   - Turn the MT3608 onboard trimpot while monitoring **VOUT+** until the output reads **~24 V** under light load.

### Test before connecting to the HAT

1. USB-C PD in → verify ~20 V at PDC004 output.
2. Verify ~24 V at J1 pin 1 (boost output).
3. Verify J1 pin 2 ≈ 20 V.
4. Confirm no excessive ripple on the 24 V output with C1 installed.

If there are any issues, it is likely the modules are faulty or DOA. Make sure to check before connecting to the HAT.

**Moreover, it is essential to use a quality PD charger, as there is little protection on these inputs. The design relies on the PD charger shutting itself off in case of a short circuit or overcurrent.**

---

## 2. Main Pi HAT (`fsae-pihat`) 

Most SMT parts are assembled at JLCPCB. The items below are hand-assembled after receiving boards.

### Hand-solder (DigiKey)

| Ref | Qty | Part |
| --- | ---: | --- |
| J2 | 1 | 2×20 extended female GPIO header (solder on **bottom**) |
| J4, J5 | 2 | 4-pos 3.5 mm top-entry terminal block |
| ETH1, ETH2 | 2 | Taoglas TMJUTHQ0021192425 RJ45 magjack (PoE) |
| FH1, FH2 | 2 | Keystone 3568 blade fuse holder + blade fuses (see silkscreen current limits: **1.5 A MAX**, **500 mA MAX**) |
| BT1 | 1 | CR1225 coin-cell holder (solder on **bottom**) |
| - | 1 | CR1225 3 V cell (insert after assembly) |
| JP1, JP2 | 2 | 1×3 2.54 mm vertical pin header |
| JP1, JP2 | 2 | Jumper shunt ([S9341-ND](https://www.digikey.ca/en/products/detail/sullins-connector-solutions/NPC02SXON-RC/2618266) or equivalent **3 A** rated) |

### Do not populate (DNP)

| Ref | Instead |
| --- | --- |
| **J1** (2×2 socket) | Solder car input / CAN harness wires directly to J1 |
| **J3** (1×3 header) | Solder USB-module harness wires directly to J3 |

### Jumpers

#### JP2 - 24 V car-rail enable

Labeled **EN** / **OFF** on silkscreen. The car rail can be disabled during bench testing without unplugging the Deutsch connector (preserves the car battery).

| Shunt position | Effect |
| --- | --- |
| **Pins 1–2** (toward **EN**) | Car 24 V rail **enabled**; required for in-car operation |
| **Removed** or on pins 2–3 (**OFF**) | Car 24 V rail **disabled**; use for bench/PD testing |

#### JP1 - CAN bus termination

| Shunt position | Effect |
| --- | --- |
| **Pins 1–2** | 120 Ω CAN termination **enabled** (use when this board is at the end of the CAN bus) |
| **Removed** or on pins 2–3 | Termination **disabled** |

### Suggested order

1. Inspect SMT work (especially buck area **U1/L1/C6** and PoE switch **U5**). Add solder on the underside of the board if there is too little on the center ground vias of the buck converter and high-side switch.
2. Solder **J2** GPIO header on the bottom.
3. Solder **BT1** on the bottom; insert CR1225 cell later.
4. Solder **ETH1**, **ETH2**, **J4**, **J5**, **FH1**, **FH2** on the top.
5. Install blade fuses in **FH1** / **FH2**.
6. Solder **JP1** and **JP2** pin headers; leave shunts off until you configure the board.
7. Set jumpers:
   - **JP2:** shunt on 1–2 for car use; remove for bench/PD-only testing.
   - **JP1:** shunt on 1–2 only if this node needs CAN termination.

### Off-board wiring summary

```text
Car Deutsch harness ──► J1 pads (24 V in, GND, CAN H/L)
USB boost module   ──► J3 pads (+24V BST, 20V USB, GND)
```

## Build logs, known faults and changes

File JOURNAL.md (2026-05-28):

# 14-05-2026 — Rev 2.5 planning and buck converter design

This project serves as a rev 2.5 of the raspberry pi DAQ (data acquisition) hat. A few months ago, I tested and diagnosed a cause of catatrophic failure of the rev 2 DAQ hat using voltage injection and a thermal camera. Although rev 3 was planned, and I am still working on it, along with others, the current failed rev 2 PCBs are still being partially used for their features that still function. This aims to be a quick revision that consolidates some of the features, while being cheap to manufacture by relying on external subpar modules (although they are expected to function perfectly fine).

I first began by planning what I would include and not include in the revision. The buck converter was essential for taking 24V from the car power LV power line and converting it to 5V for the Raspberry Pi. Existing modules cut too many corners to be reliable for this use, especially at 3A peak current. However, rev 2 also included a boost converter to boost 20V PD to 24V for injecting PoE for the base station antenna, and for ease of powering during testing. Since the current here would be pretty low, I decided to use a MT3608 and PDC004 PD module (I already have one, and the design seems pretty good; really big power plane on bottom) on a separate PCB.

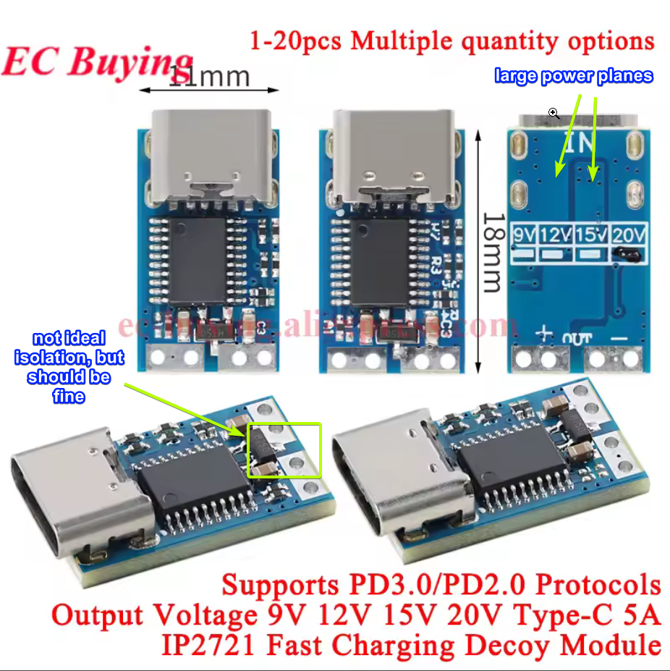
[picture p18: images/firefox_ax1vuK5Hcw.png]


The MT3608 module also should be able to handle the current required (2A) for the 24V PoE injection, which should be around 1A peak. The IC itself is pretty capable, there often just isn't a great component selection or insufficient decoupling/filtering. I remebered [this greatscott video](https://www.youtube.com/watch?v=6bicunweBAQ) where he added a 2.2uF 1210 capacitor to the output of the MT3608 to improve stability, so I thought with that, it should be very sufficient for my application.



I began with designing the buck with TI WEBENCH power designer, which I had some experience using before. But first, I wanted to select a buck converter that was relatively cheap and had a low component count. I started with JLCPCB basic parts, and found the TPS5430, which seemed to fit all my requirements. After some part selection (finding available inductor and output tantalum cap on LCSC), I settled with a design/layout idea. I drafted some of the schematic together, but still a lot to work on.

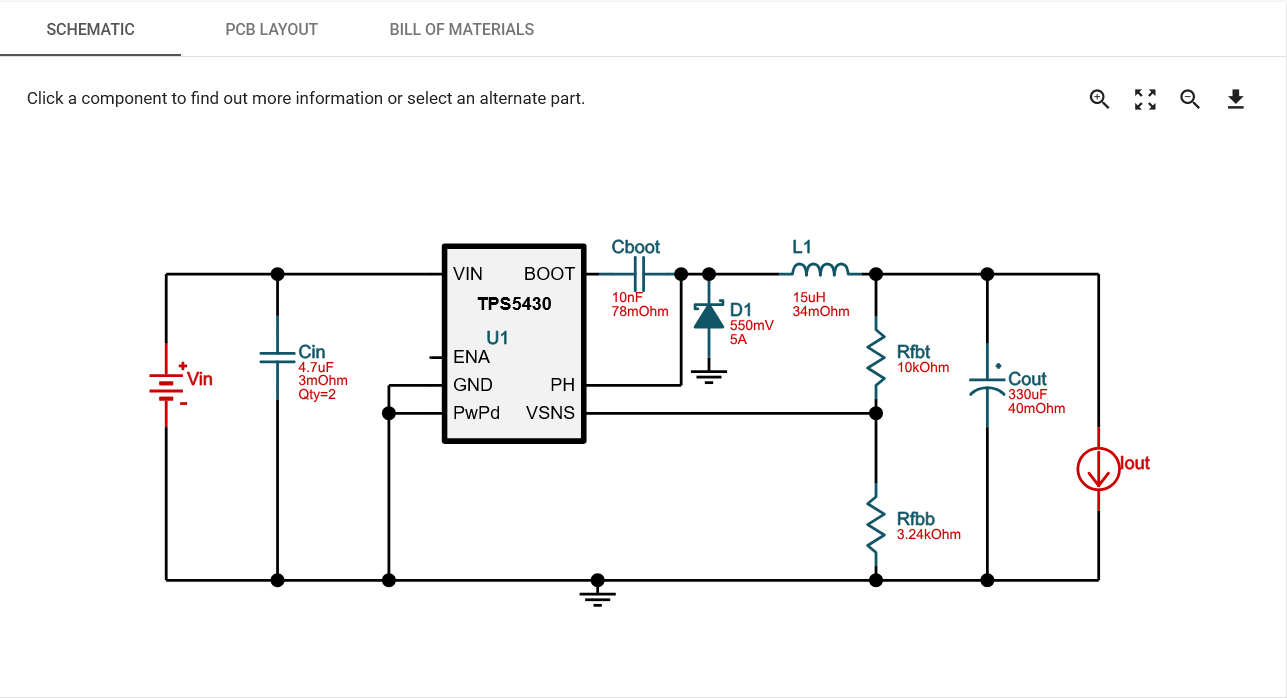
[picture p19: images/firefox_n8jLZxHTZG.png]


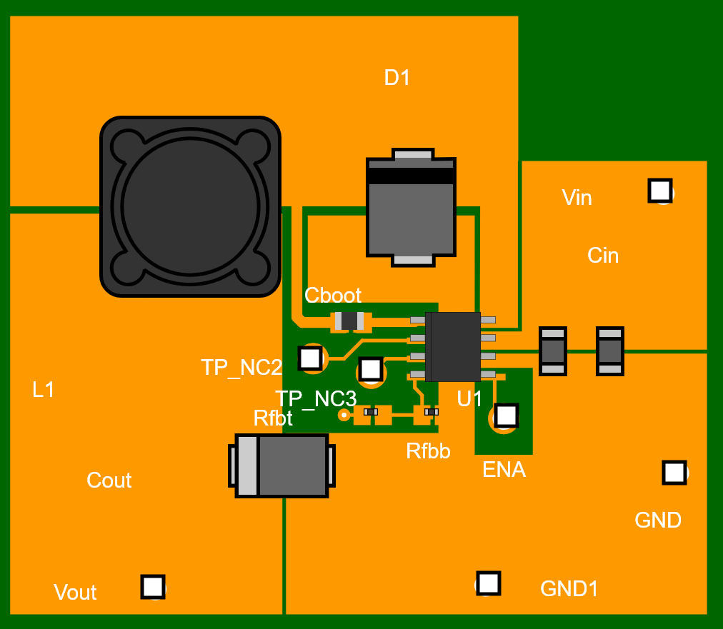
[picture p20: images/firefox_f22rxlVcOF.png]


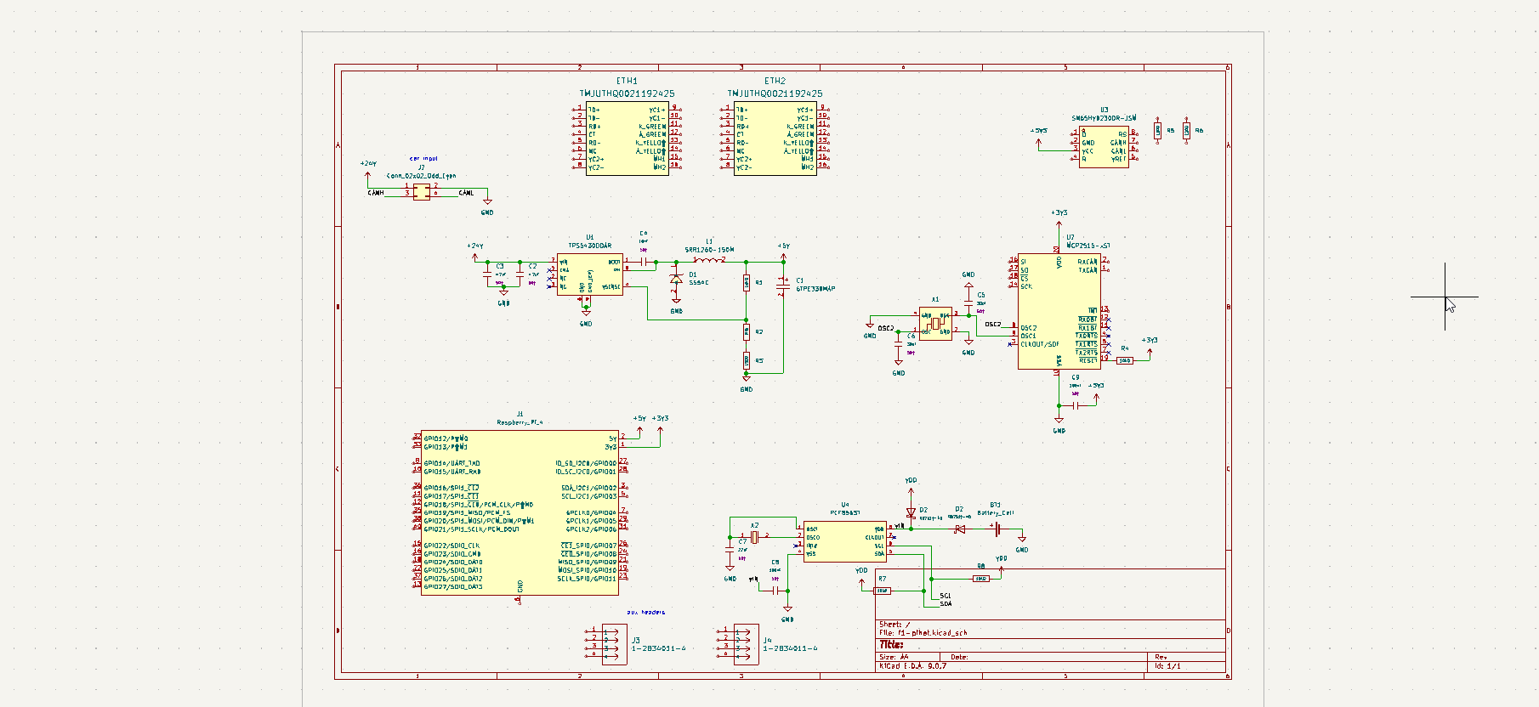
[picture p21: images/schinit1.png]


Total time spent: 4 hours

# 15-05-2026 — Input protection and schematic completion

I started by looking into input protection from the car on the 24V rail. I decided to use a polyfuse and TVS diode to protect the input from overvoltage/transients and overcurrent. I took some component selection inspiration from [this waveshare module](https://www.waveshare.com/wiki/2-CH_CAN_HAT+), which does the CAN and HV power input for powering the RPi. I also spent some time finishing up the rest of the schematic (importing components for terminal blocks + ethernet) and trying to keep things somewhat organized.

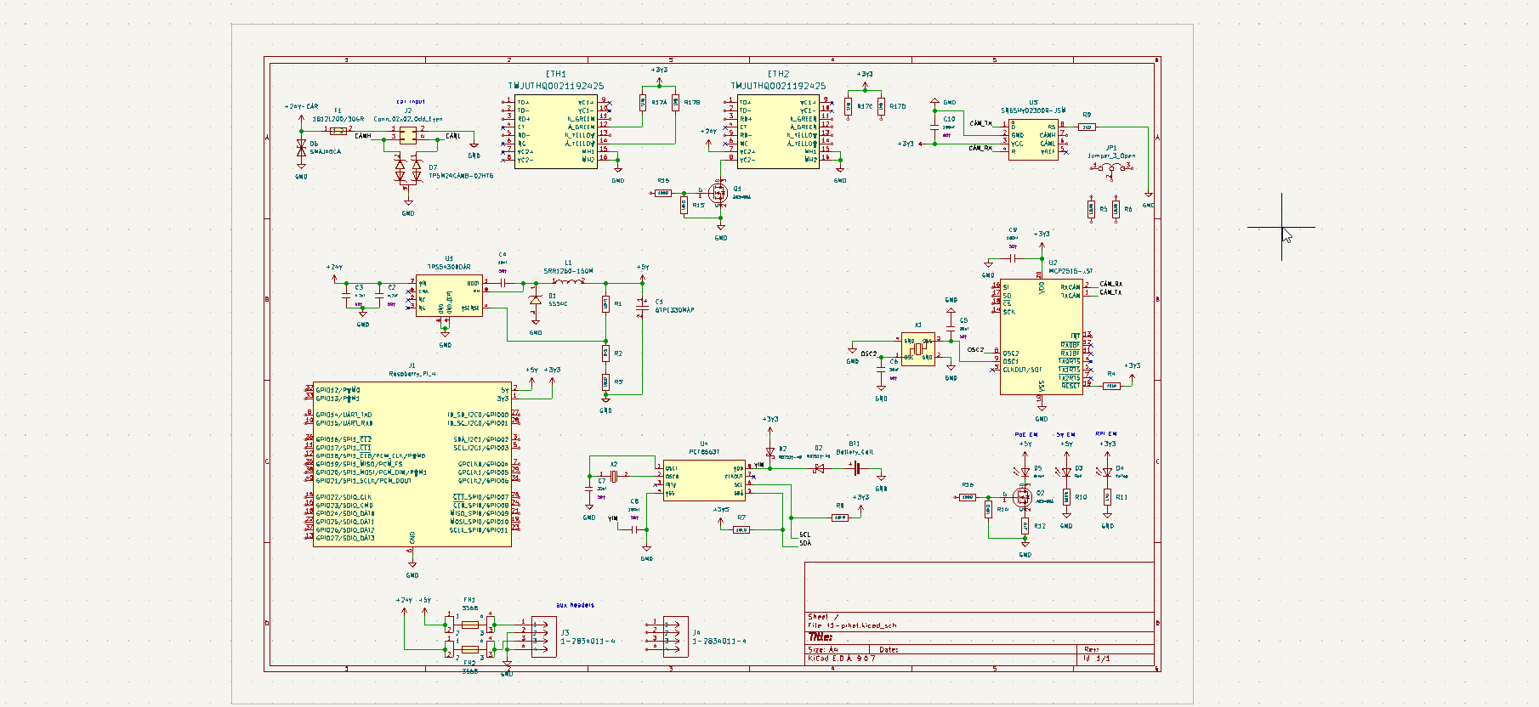
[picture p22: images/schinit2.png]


I also switched some of the power logic later on, to make sure 20V PD was OR'd to the buck and not 24V Boost, to reduce strain on the boost converter and to make sure there's less ripple on the 5V rail (since having 20V -> 24V -> 5V is less ripple than having 20V -> 5V). I eventually finished up the schematic (for now, still need to confirm with a few team members) and imported it to the PCB layout.

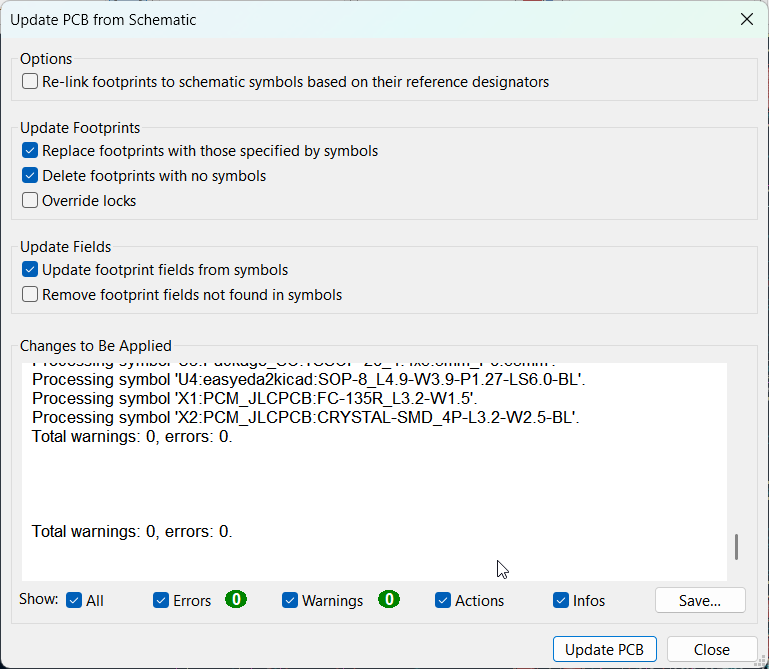
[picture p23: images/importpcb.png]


Routing sure is going to be fun.

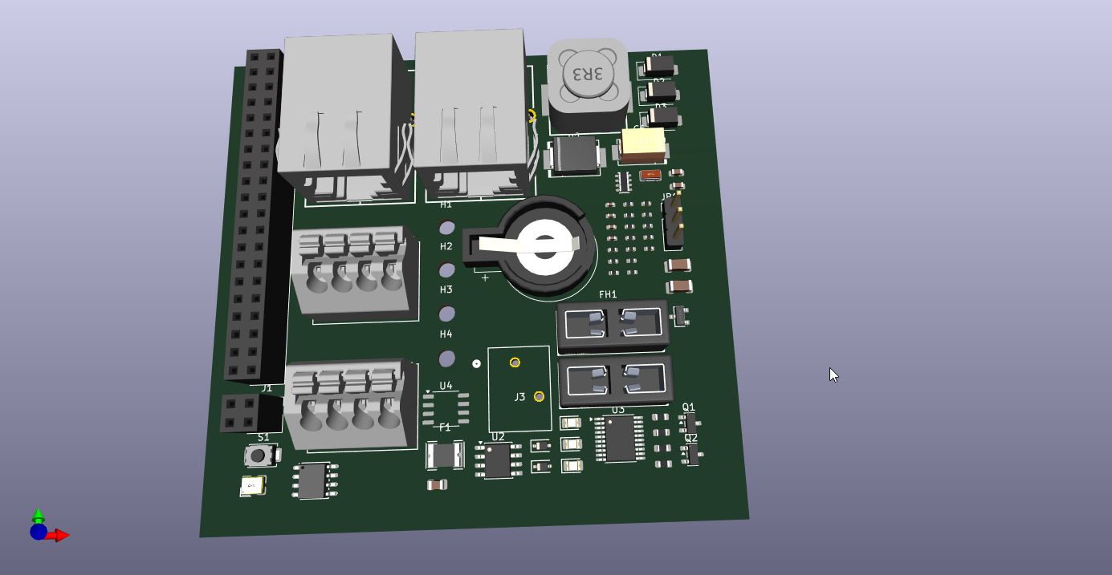
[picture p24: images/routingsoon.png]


Total time spent: 3 hours

# 18-05-2026 — Buck converter PCB layout

I started the day by setting up the board and mounting holes based on the RPi mechanical drawings and trying to route the buck converter, as I knew I would need to route the rest of the board around it.

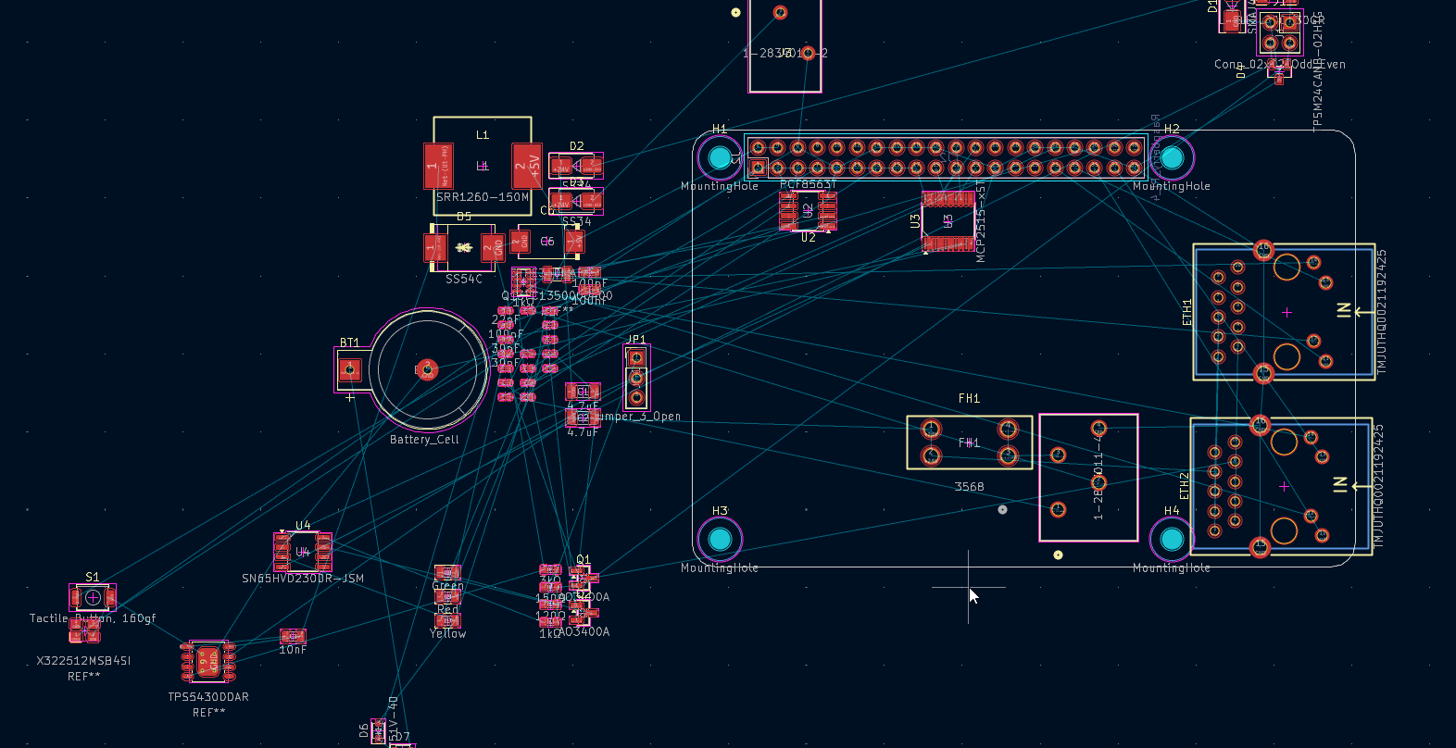
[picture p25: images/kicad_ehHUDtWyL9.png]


I also needed to route the ethernet and terminal blocks, which would be a pain. I had also never used filled polygons before for routing, so it took a while to get the hang of it after watching a few videos of laying out switching power supplies. One thing I quickly realized was that the provided recommended layout was not the best:

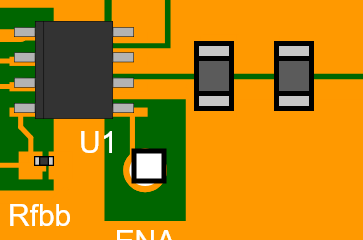
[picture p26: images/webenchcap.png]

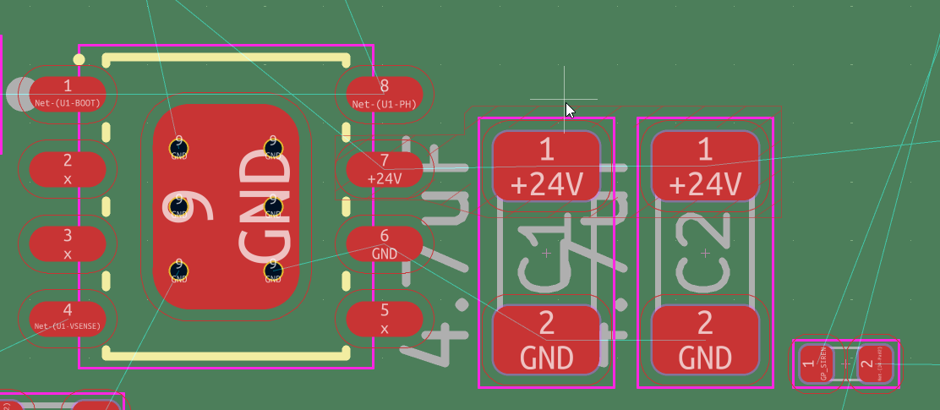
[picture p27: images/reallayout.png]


After some trial and error, and asking in the Slack for a review, I was able to get something pretty good.

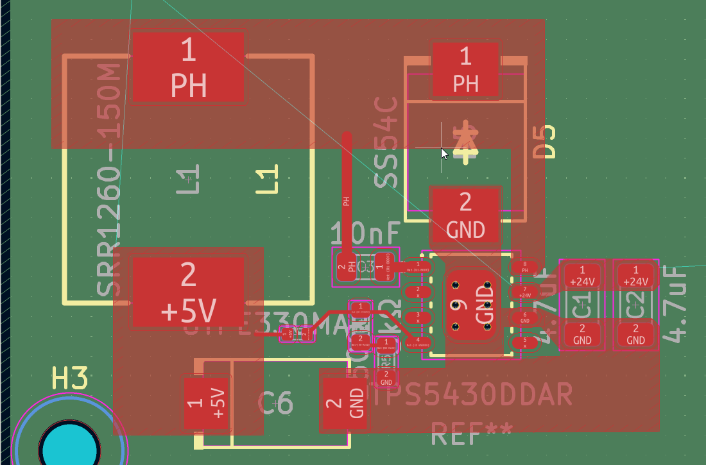
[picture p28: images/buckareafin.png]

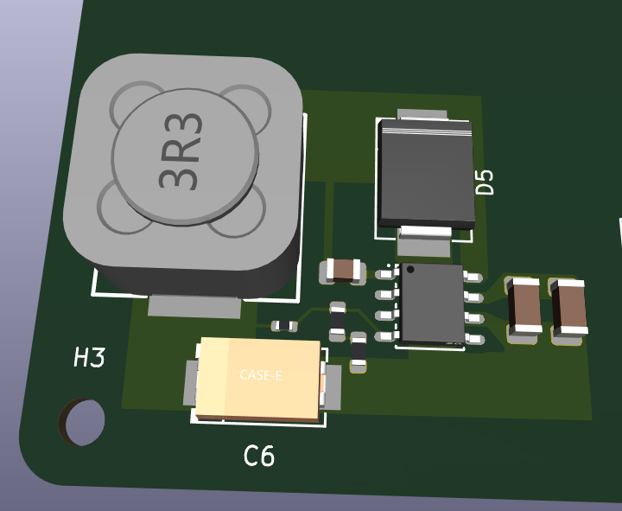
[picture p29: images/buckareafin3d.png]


I had removed the 2nd auxillary terminal block earlier today as I thought it wasn't going to fit on the board, but looking at it again after laying some things out, it should be able to fit. I might add it back in later depending on how the routing goes.

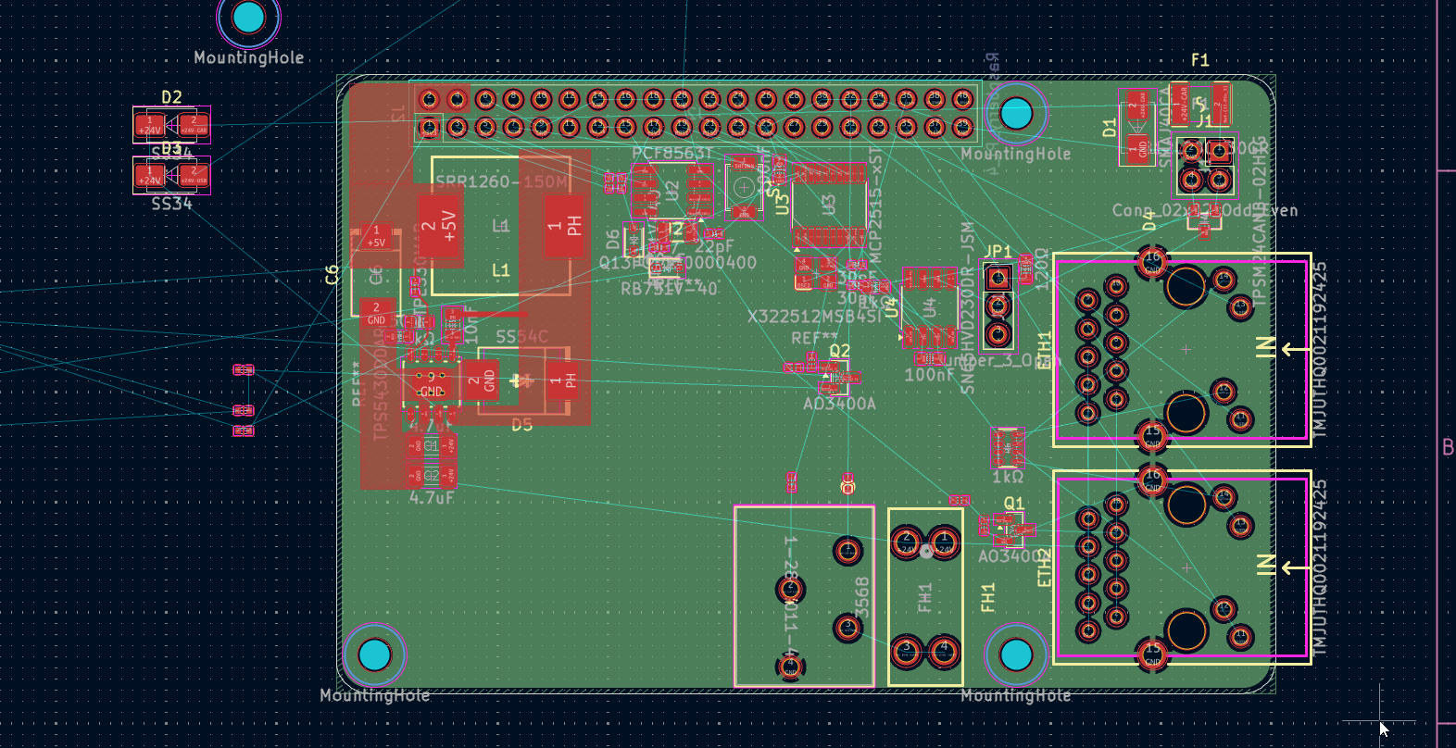
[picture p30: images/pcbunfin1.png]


Total time spent: 4 hours

# 19-05-2026 — PoE switch, LEDs, and ethernet routing

My initial PoE switch was a low-side switch, since it was the easiest to implelement. Howeever after searching for a bit, I realized that a high-side switch would be better for this application due to external issues that could arise with floating ground. Since the PoE is 24V, a P-Ch MOSFET would be a bit difficult to implement as most have a max Vgs of +/-20V. I looked into high-side driver ICs and decided to roll with that instead. After some searching on LCSC, I found a good one from TI (TPS1H200A), which is made for automotive applications and is very flexible. It has a lot of builtin protection and diagnostic reporting, and is quite cheap ($0.75). And it can handle up to 2.5A with overcurrent protection.

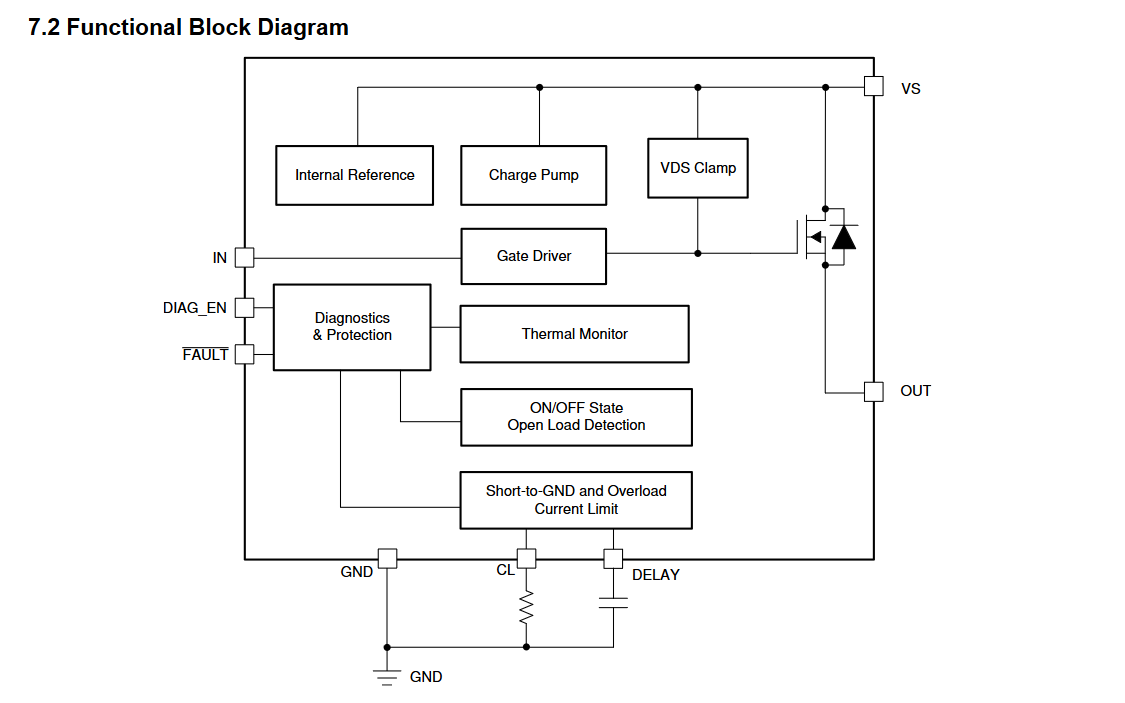
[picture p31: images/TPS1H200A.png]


Another thing that annoyed me was the different brightness of LEDs on the status indicators of Rev 2, since all colour LEDs used the same resistors, so I tried to compensate for that by using a different resistance for each colour LED.

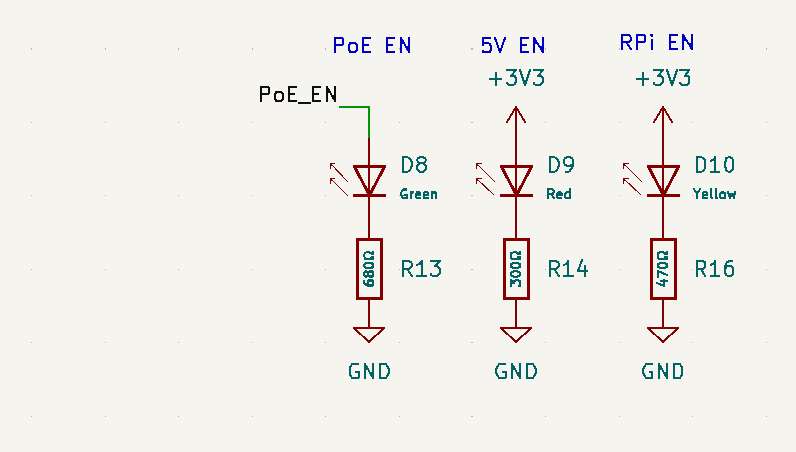
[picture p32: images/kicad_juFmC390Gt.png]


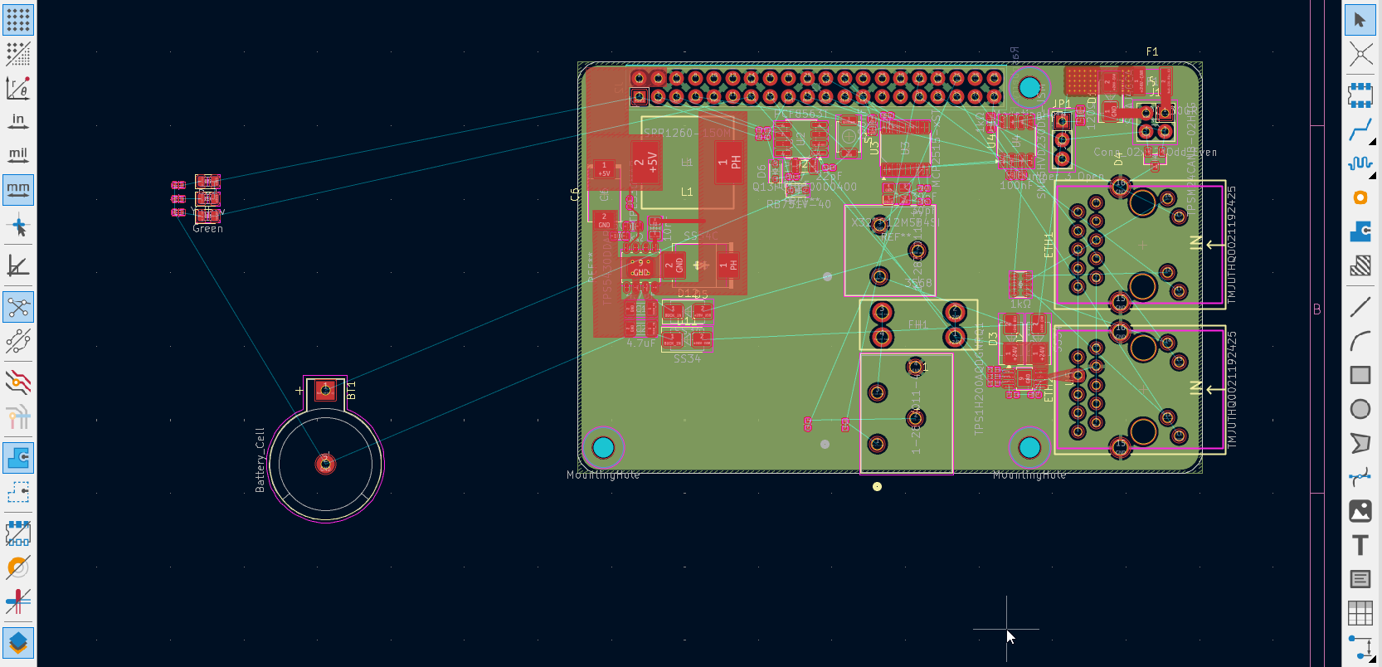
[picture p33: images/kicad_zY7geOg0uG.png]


I also added the footprint for the coin cell battery holder I wanted to use, which I had to do manually since the TE component didn't have a footprint. After talking to another team member, I also switched the PD/Boost module header from a 3-pin terminal block to 3 pin headers to reduce the footprint; it would be connected with: holes - wires - Deutsch connectors - wires - usb c breakout.

Lastly, I decided to tackle the ethernet routing. The impedance matching wasn't too bad and got over that pretty easily, but I quickly realized the routing was not going to be wasy due to the layout.

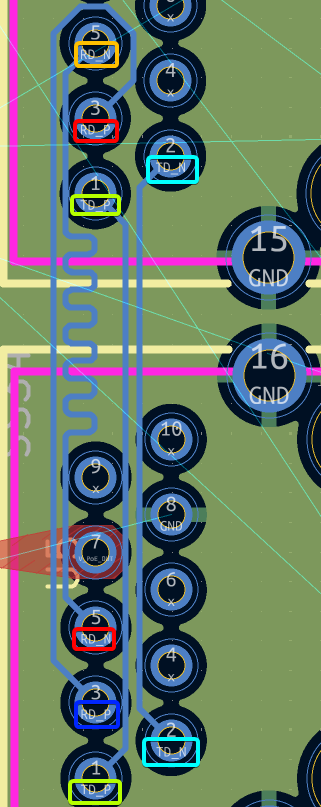
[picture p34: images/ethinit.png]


This was my first attempt, which very much wasn't ideal. I tried some more for a while and eventually asked for help in the Slack, but got no response. I asked a team member for help, and he sent me a rough example of how he would do it. I did mine based on that, and it turned out pretty good.

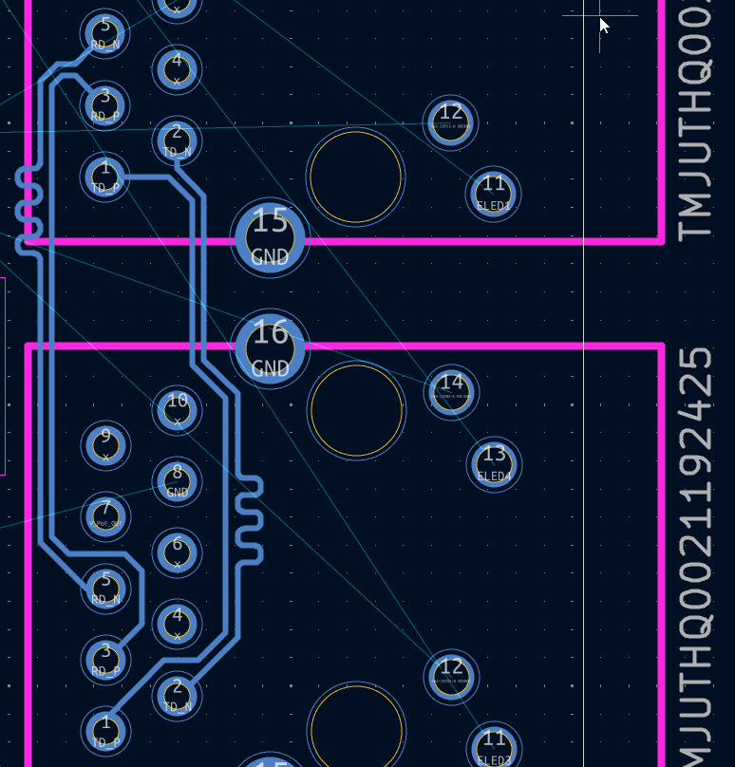
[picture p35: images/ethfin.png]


Total time spent: 5 hours

# 20-05-2026 — Boost/PD module and main PCB routing

I began with working on the external boost + PD module. I got the MT3608 module symbol + footprint online, but slightly modified to make sure it would fit variations of the board too. Just as a check, I also found a STEP model on GrabCAD and imported it to Kicad to make sure it would fit on the footprint. I had already made the PD module symbol and footprint on Altium, so I imported it to Kicad.



For the PCB, I made the PD module surface mount on the bottom and the MT3608 on the top, since both have large pads on both sides with vias.





I also decided to add back the auxillary terminal block, which was easy to place since I had every other component approximatly in place.

After spending about an hour cleaning up the schematic (it was quite difficult to fit everything in), I started the final stretch of routing the logic components and adding silkscreen labels.

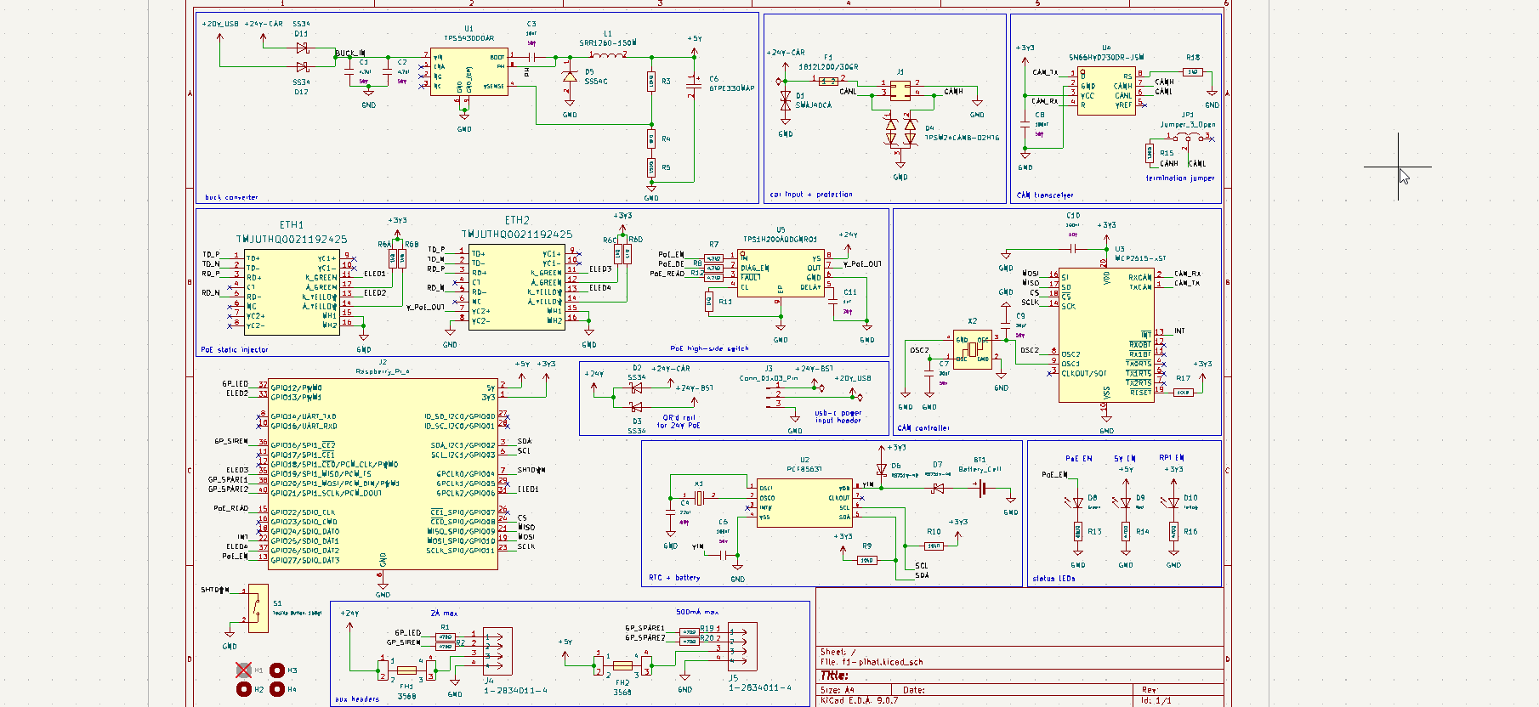
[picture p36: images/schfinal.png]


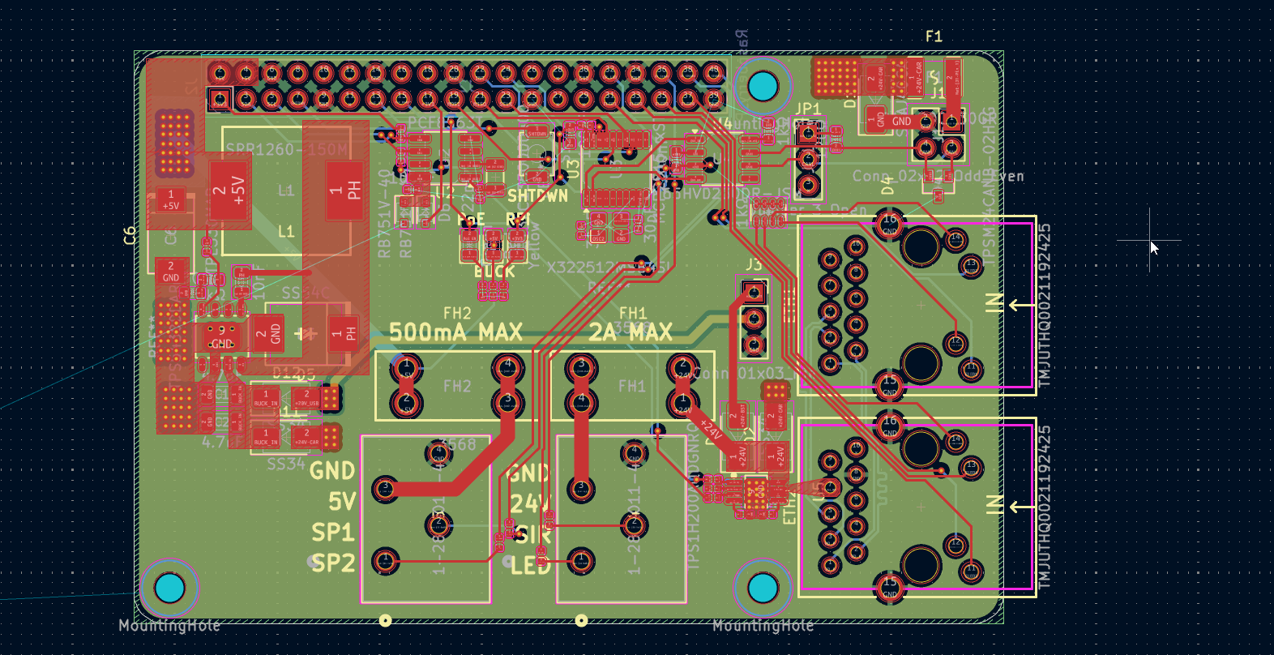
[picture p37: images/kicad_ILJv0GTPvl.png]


This is about what I have so far, just need to route grounds to the ground plane and route a few more minor things. I also realized that a 20mm dia cell would be too big because of the vias I added near the buck, which is where I planned to mount the cell (on the bottom). I decided to switch to a 12mm dia cell, and manually added the footprint for the TE mount (CR1225).

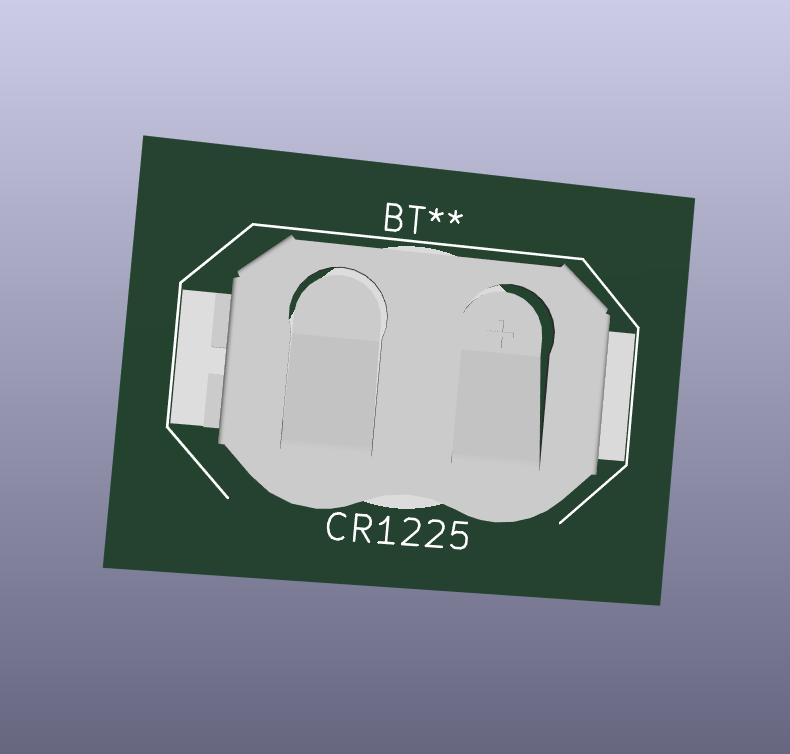
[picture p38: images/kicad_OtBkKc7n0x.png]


Total time spent: 5 hours

# 21-05-2026 — Final routing, review feedback, and production prep

I started off by finishing the routing and uploading the pcb files to github. I also asked for a review in the Slack, but after not getting a response, I send the schematic and pcb for the subteam lead to review. He had concerns about power switching, since during testing it was important to preserve the car's battery as much as possible. He suggested I add a jumper to select between 24V Car rail and the 24V Boost+20V PD rail. However, since this would require a DPDT switch in my current configuration (it would be possible if the boost converter was just on the board, which is the case for rev 3), I decided to just add a jumper to the input of the 24V Car rail, so it could be disabled without unplugging the Deutsch connector.



I also selected some high current jumpers with a grip section on Digikey. Moreover, I got asked to select a strobe light and buzzer for the base station, which woud be used only in testing. Since they weren't too important in terms of performance or importance, I selected some cheap ones from AliExpress.

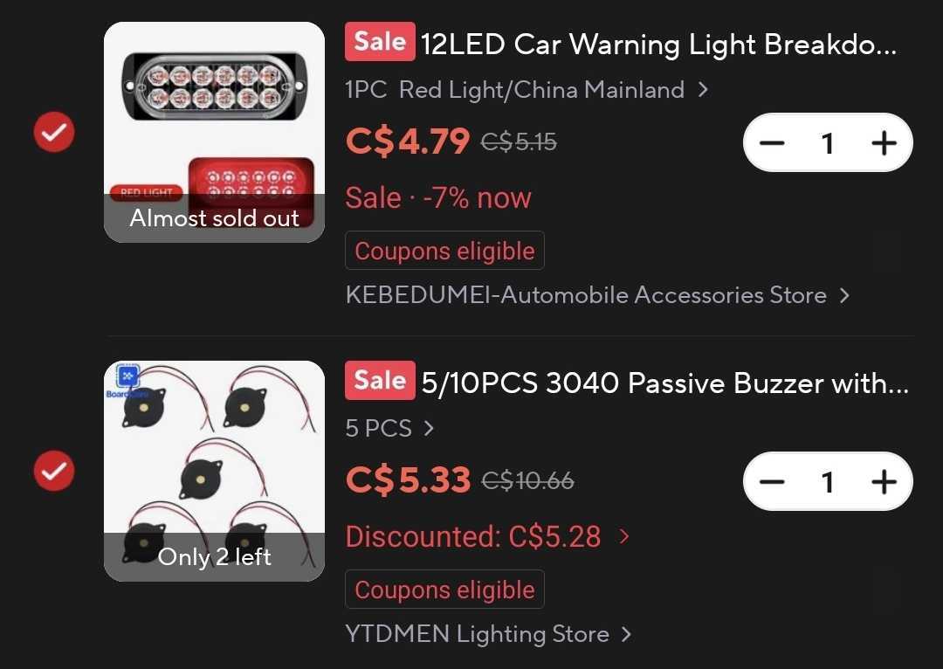
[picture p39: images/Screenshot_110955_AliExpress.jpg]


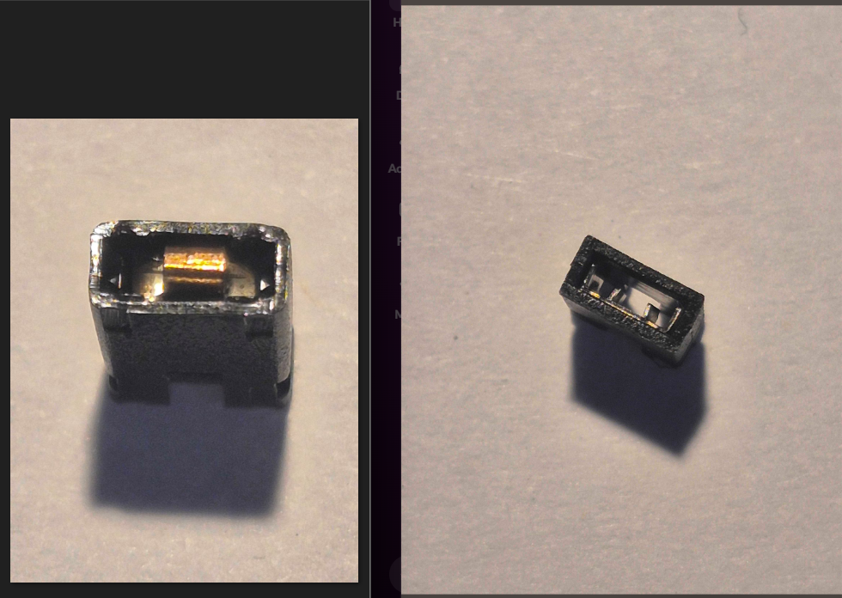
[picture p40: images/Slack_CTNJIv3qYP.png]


High vs low current rated jumpers.

Lastly, I spent some time polishing some routing, adding prod files and confirming they upload to JLCPCB, and creating a README.

Total time spent: 4 hours

# 22-05-2026 — Documentaton and Github

I spent a while adding BOM, formatting the README, adding the production files to Github, and adding assembly instructions. I made it such that it is extremely easy to manufacture and assemble for anyone following, with BOMs for both JLCPCB and DigiKey, and easy to find production files for JLCPCB.

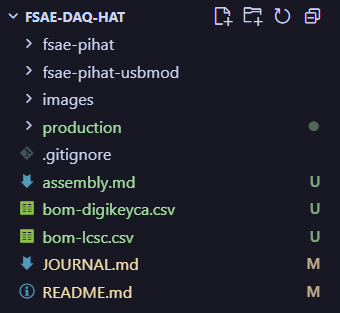
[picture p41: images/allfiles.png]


Total time spent: 1.5 hours

# 26-05-2026 — Small updates

I adjusted the PCB design a bit after reading an updated version of the TPS5430 datasheet, which explicitly states that the input decoupling capacitors should be placed under 1mm to the VIN and GND pins, so moved them a bit closer and added in a 3rd capacitor. On WeBENCH, when simulating with a lower input voltage, it suggested adding more decoupling so I added another identical 4.7uF capacitor. 



I also found a new usb c pd trigger module on aliexpress that has a better design (more isolation between + and - output), is adjustable, has an indicator LED, and uses a branded HUSB238 chip. I ordered one and will be testing it out soon, but it looks a lot more reliable than the previous one, which uses an unknown chip and is not easily adjustable (even though it technically is, it's just not documented well). I also noticed a mistake on my design missing a pullup, which I added in. I also improved some of the routing and added some PCB art.

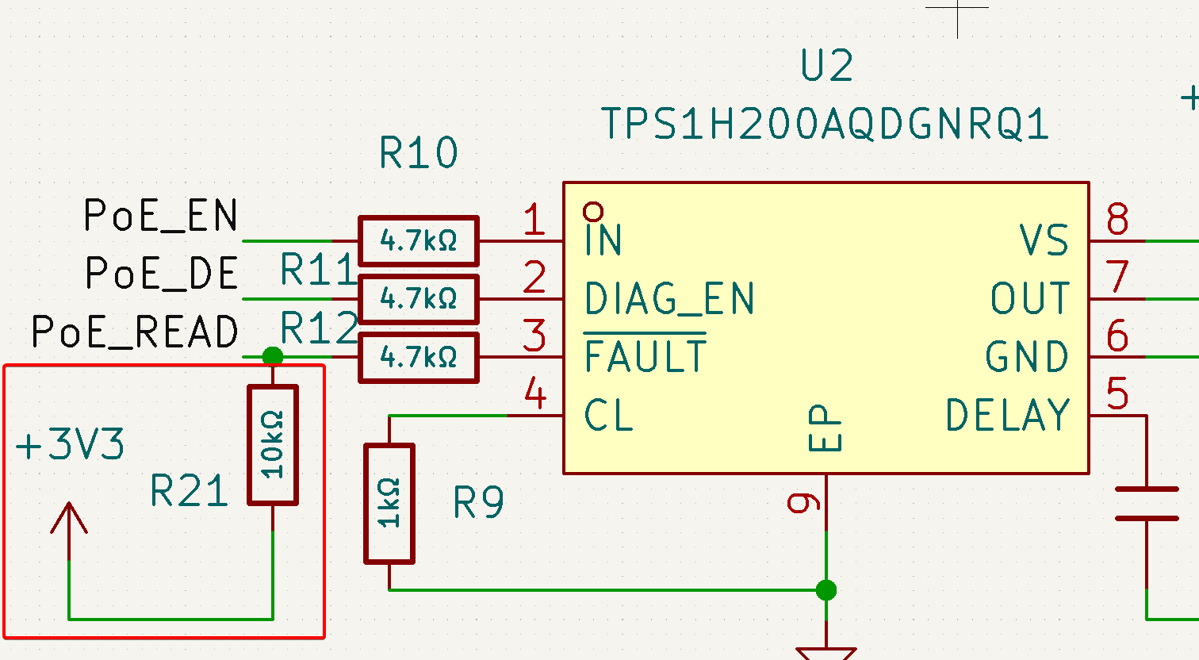
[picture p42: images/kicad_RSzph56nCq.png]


Total time spent: 1 hour

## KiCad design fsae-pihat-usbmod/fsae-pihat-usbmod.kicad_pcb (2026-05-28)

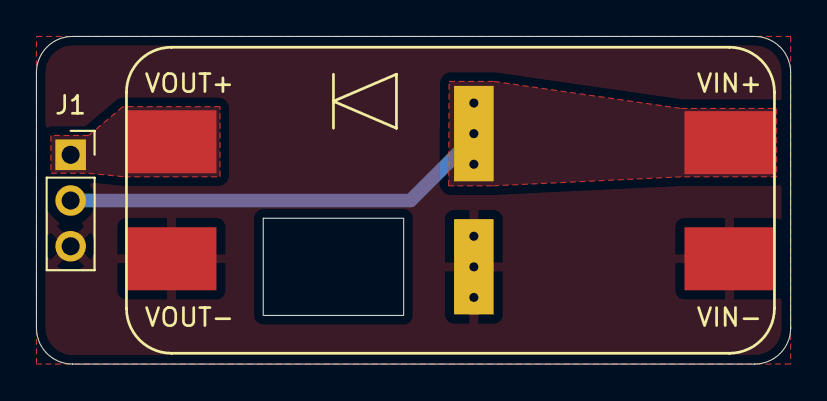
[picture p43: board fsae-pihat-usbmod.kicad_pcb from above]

Board: 2 copper layers, 41.9 x 18.2 mm, 3 parts (1 on the bottom side), 3 nets.

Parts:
J1: Conn_01x03_Socket; PinSocket_1x03_P2.54mm_Vertical
J2: HUSB238 Module; HUSB238_module_purple
U1: MT3608 Boost; MT3608_module_SMT

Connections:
+20V: J1.2, J2.1 (OUT+), U1.1 (VIN+)
+24V: J1.1, U1.4 (VOUT-)
GND: J1.3, J2.2 (OUT-), U1.2 (VIN-), U1.3 (VOUT-)

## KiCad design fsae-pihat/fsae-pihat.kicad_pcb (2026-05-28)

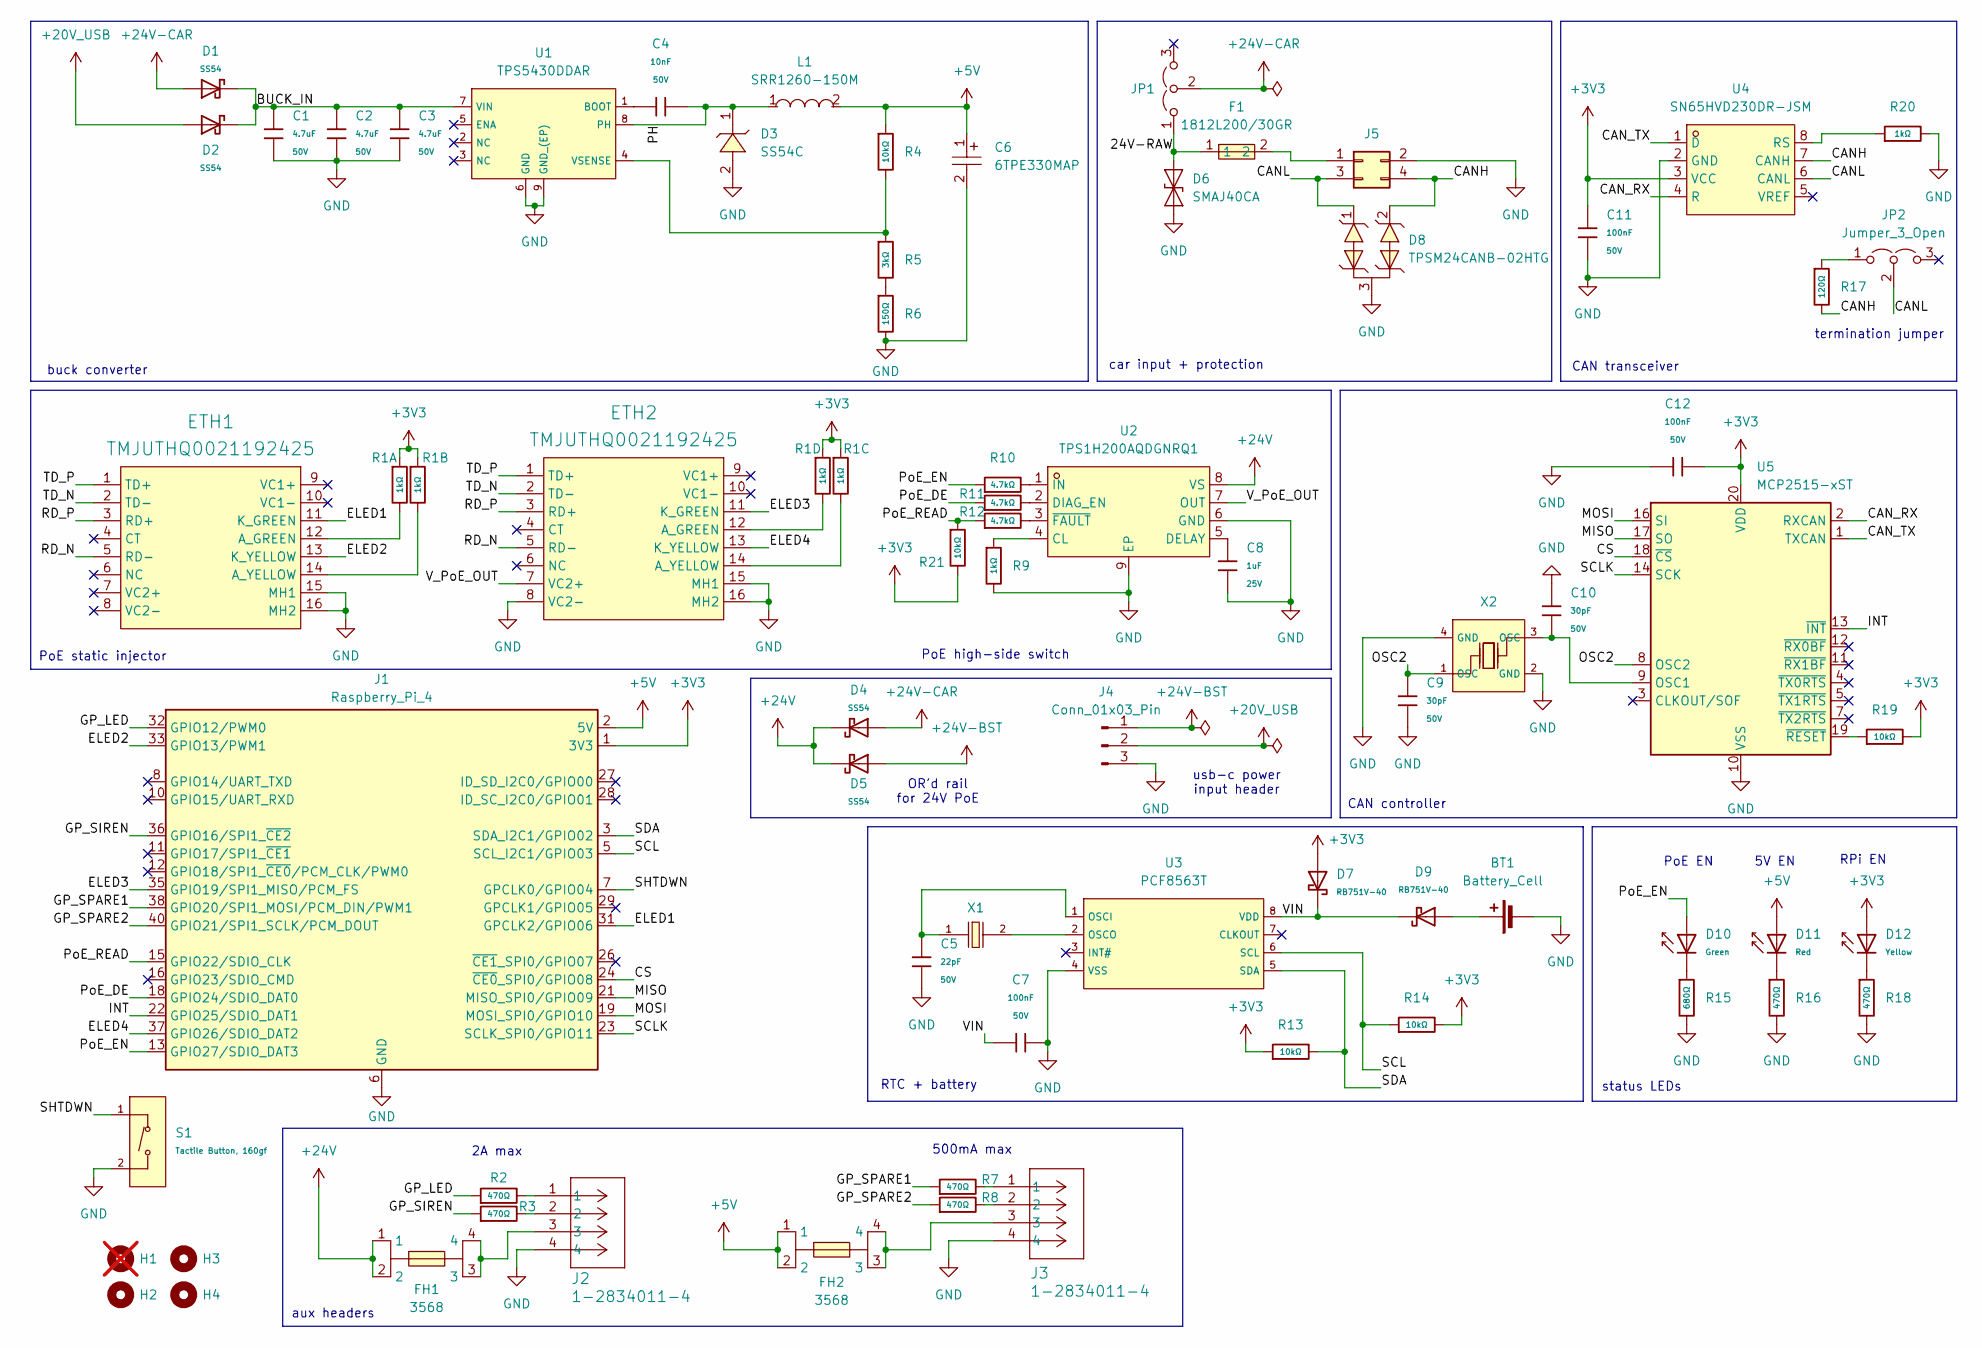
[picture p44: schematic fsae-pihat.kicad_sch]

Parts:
BT1: Battery_Cell; BAT-HLD-012-SMT-TR
C1, C2, C3: 4.7uF; C_1206; Voltage Rated 50V; Tolerance ±10%; Part 1206B475K500NT; LCSC C29823
C4: 10nF; C_0805; Voltage Rated 50V; Tolerance ±10%; Part CL21B103KBANNNC; LCSC C1710
C5: 22pF; C_0402; Voltage Rated 50V; Tolerance ±5%; Part 0402CG220J500NT; LCSC C1555
C6: 6TPE330MAP; CAP-SMD_L7.3-W4.3-R-RD; MPN 6TPE330MAP; LCSC Part C79112
C7: 100nF; C_0402; Voltage Rated 50V; Tolerance ±10%; Part CL05B104KB54PNC; LCSC C307331
C8: 1uF; C_0402; Voltage Rated 25V; Tolerance ±10%; Part CL05A105KA5NQNC; LCSC C52923
C9, C10: 30pF; C_0402; Voltage Rated 50V; Tolerance ±5%; Part 0402CG300J500NT; LCSC C1570
C11, C12: 100nF; C_0603; Voltage Rated 50V; Tolerance ±10%; Part CC0603KRX7R9BB104; LCSC C14663
D1, D2, D4, D5: SS54; D_SMA; Forward Voltage (Vf@If) 0.55V@5.0A; Reverse Voltage (Vr) 40V; Part SS54; LCSC C7420369
D3: SS54C; SMC_L6.9-W5.9-LS7.9-RD; MPN SS54C; LCSC Part C18199188
D6: SMAJ40CA; D_SMA
D7, D9: RB751V-40; D_SOD-323; Forward Voltage (Vf@If) 370mV@1mA; Reverse Voltage (Vr) 40V; Part RB751V-40; LCSC C7502691
D8: TPSM24CANB-02HTG; SOT-23-3_L2.9-W1.3-P1.90-LS2.4-BR; MPN TPSM24CANB-02HTG; LCSC Part C970029
D10: Green; D_0805; Part KT-0805G; LCSC C2297
D11: Red; D_0805; Forward Voltage (VF) 1.6V~2.6V; Part NCD0805R1; LCSC C84256
D12: Yellow; D_0805; Part KT-0805Y; LCSC C2296
ETH1, ETH2: TMJUTHQ0021192425; Manufacturer Part Number TMJUTHQ0021192425
F1: 1812L200/30GR; F1812; MPN 1812L200/30GR; LCSC Part C18198342
FH1, FH2: 3568; FUSE-SMD_4P-L16.0-W6.7-P3.40; MPN 3568; LCSC Part C5249699
H1: MountingHole; MountingHole_2.7mm_M2.5; not fitted
H2, H3, H4: MountingHole; MountingHole_2.7mm_M2.5
J1: Raspberry_Pi_4; PinSocket_2x20_P2.54mm_Vertical
J2, J3: 1-2834011-4; CONN_1-2834011-4_TEC
J4: Conn_01x03_Pin; PinSocket_1x03_P2.54mm_Vertical
J5: Conn_02x02_Odd_Even; PinSocket_2x02_P2.54mm_Vertical
JP1, JP2: Jumper_3_Open; PinHeader_1x03_P2.54mm_Vertical
L1: SRR1260-150M; IND-SMD_L12.5-W12.5_GSDRK127P; MPN SRR1260-150M; LCSC Part C2041333
R1: 1kΩ; R_0603x4; Tolerance ±5%; Part 4D03WGJ0102T5E; LCSC C20197
R2, R3, R7, R8, R16, R18: 470Ω; R_0402; Overload Voltage (Max) 50V; Tolerance ±1%; Part 0402WGF4700TCE; LCSC C25117
R4, R13, R14, R19, R21: 10kΩ; R_0402; Overload Voltage (Max) 50V; Tolerance ±1%; Part 0402WGF1002TCE; LCSC C25744
R5: 3kΩ; R_0603; Overload Voltage (Max) 75V; Tolerance ±1%; Part 0603WAF3001T5E; LCSC C4211
R6: 150Ω; R_0603; Overload Voltage (Max) 75V; Tolerance ±1%; Part 0603WAF1500T5E; LCSC C22808
R9: 1kΩ; R_0402; Overload Voltage (Max) 50V; Tolerance ±1%; Part 0402WGF1001TCE; LCSC C11702
R10, R11, R12: 4.7kΩ; R_0402; Overload Voltage (Max) 50V; Tolerance ±1%; Part 0402WGF4701TCE; LCSC C25900
R15: 680Ω; R_0402; Overload Voltage (Max) 50V; Tolerance ±1%; Part 0402WGF6800TCE; LCSC C25130
R17: 120Ω; R_0603; Overload Voltage (Max) 75V; Tolerance ±1%; Part 0603WAF1200T5E; LCSC C22787
R20: 1kΩ; R_0603; Overload Voltage (Max) 75V; Tolerance ±1%; Part 0603WAF1001T5E; LCSC C21190
S1: Tactile Button, 160gf; SW_SPST_TS-1088-xR020; Voltage Rating (Dc) 12V; Part TS-1088-AR02016; LCSC C720477
U1: TPS5430DDAR; ESOP-8_L4.9-W3.9-P1.27-LS6.0-TL-EP; Output Voltage 1.221V~32.04V; Input Voltage 5.5V~36V; Part TPS5430DDAR; LCSC C9864
U2: TPS1H200AQDGNRQ1; EMSOP-8_L3.0-W3.0-P0.65-LS4.9-BL-EP-A; MPN TPS1H200AQDGNRQ1; LCSC Part C2653785
U3: PCF8563T; SOIC-8_3.9x4.9mm_P1.27mm; Operating Voltage 1V~5.5V; Part PCF8563T/5,518; LCSC C7440
U4: SN65HVD230DR-JSM; SOP-8_3.9x4.9mm_P1.27mm; MPN SN65HVD230DR-JSM; LCSC Part C46596299
U5: MCP2515-xST; TSSOP-20_4.4x6.5mm_P0.65mm
X1: Q13FC1350000400; FC-135R_L3.2-W1.5; Frequency Tolerance ±20ppm; Part Q13FC13500004; LCSC C32346
X2: X322512MSB4SI; CRYSTAL-SMD_4P-L3.2-W2.5-BL; Frequency Tolerance ±10ppm; Part X322512MSB4SI; LCSC C9002

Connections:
+3V3: C11.1, C12.2, D7.2, D12.2, J1.1 (3V3), J1.17 (3V3), R1.1, R1.2, R1.3, R1.4, R13.1, R14.2, R19.2, R21.2, U4.3 (VCC), U5.20 (VDD)
+5V: C6.1, D11.2, FH2.1, FH2.2, J1.2 (5V), J1.4 (5V), L1.2, R4.1
+20V_USB: D2.2, J4.2
+24V: D4.1, D5.1, FH1.1, FH1.2, U2.8 (VS)
+24V-BST: D5.2, J4.1
+24V-CAR: D1.2, D4.2, JP1.2 (C)
/24V-RAW: D6.2 (A2), F1.1, JP1.1 (A)
/BUCK_IN: C1.1, C2.1, C3.1, D1.1, D2.1, U1.7 (VIN)
/CANH: D8.2, J5.4, R17.2, U4.7 (CANH)
/CANL: D8.1, J5.3, JP2.2 (C), U4.6 (CANL)
/CAN_RX: U4.4 (R), U5.2 (RXCAN)
/CAN_TX: U4.1 (D), U5.1 (TXCAN)
/CS: J1.24 (~CE0_SPI0/GPIO08), U5.18 (~CS)
/ELED1: ETH1.11 (K_GREEN), J1.31 (GPCLK2/GPIO06)
/ELED2: ETH1.13 (K_YELLOW), J1.33 (GPIO13/PWM1)
/ELED3: ETH2.11 (K_GREEN), J1.35 (GPIO19/SPI1_MISO/PCM_FS)
/ELED4: ETH2.13 (K_YELLOW), J1.37 (GPIO26/SDIO_DAT2)
/GP_LED: J1.32 (GPIO12/PWM0), R2.1
/GP_SIREN: J1.36 (GPIO16/SPI1_~CE2), R3.1
/GP_SPARE1: J1.38 (GPIO20/SPI1_MOSI/PCM_DIN/PWM1), R7.1
/GP_SPARE2: J1.40 (GPIO21/SPI1_SCLK/PCM_DOUT), R8.1
/INT: J1.22 (GPIO25/SDIO_DAT1), U5.13 (~INT)
/MISO: J1.21 (MISO_SPI0/GPIO09), U5.17 (SO)
/MOSI: J1.19 (MOSI_SPI0/GPIO10), U5.16 (SI)
/OSC2: C9.1, U5.8 (OSC2), X2.1 (OSC)
/PH: C4.2, D3.1, L1.1, U1.8 (PH)
/PoE_DE: J1.18 (GPIO24/SDIO_DAT0), R11.1
/PoE_EN: D10.2, J1.13 (GPIO27/SDIO_DAT3), R10.1
/PoE_READ: J1.15 (GPIO22/SDIO_CLK), R12.1, R21.1
/RD_N: ETH1.5 (RD-), ETH2.5 (RD-)
/RD_P: ETH1.3 (RD+), ETH2.3 (RD+)
/SCL: J1.5 (SCL_I2C1/GPIO03), R14.1, U3.6 (SCL)
/SCLK: J1.23 (SCLK_SPI0/GPIO11), U5.14 (SCK)
/SDA: J1.3 (SDA_I2C1/GPIO02), R13.2, U3.5 (SDA)
/SHTDWN: J1.7 (GPCLK0/GPIO04), S1.1 (A)
/TD_N: ETH1.2 (TD-), ETH2.2 (TD-)
/TD_P: ETH1.1 (TD+), ETH2.1 (TD+)
/VIN: C7.1, D7.1, D9.1, U3.8 (VDD)
/V_PoE_OUT: ETH2.7 (VC2+), U2.7 (OUT)
GND: BT1.2 (-), C1.2, C2.2, C3.2, C5.2, C6.2, C7.2, C8.2, C9.2, C10.1, C11.2, C12.1, D3.2, D6.1 (A1), D8.3, ETH1.15 (MH1), ETH1.16 (MH2), ETH2.8 (VC2-), ETH2.15 (MH1), ETH2.16 (MH2), J1.6 (GND), J1.9 (GND), J1.14 (GND), J1.20 (GND), J1.25 (GND), J1.30 (GND), J1.34 (GND), J1.39 (GND), J2.4, J3.4, J4.3, J5.2, R6.2, R9.2, R15.2, R16.2, R18.2, R20.2, S1.2 (B), U1.6 (GND), U1.9 (GND_(EP)), U2.6 (GND), U2.9 (EP), U3.4 (VSS), U4.2 (GND), U5.10 (VSS), X2.2 (GND), X2.4 (GND)
unnamed: BT1.1 (+), D9.2
unnamed: D10.1, R15.1
unnamed: D11.1, R16.1
unnamed: D12.1, R18.1
unnamed: ETH1.12 (A_GREEN), R1.8
unnamed: ETH1.14 (A_YELLOW), R1.7
unnamed: ETH2.12 (A_GREEN), R1.5
unnamed: ETH2.14 (A_YELLOW), R1.6
unnamed: FH1.3, FH1.4, J2.3
unnamed: FH2.3, FH2.4, J3.3
unnamed: J2.1, R2.2
unnamed: J2.2, R3.2
unnamed: J3.1, R7.2
unnamed: J3.2, R8.2
unnamed: F1.2, J5.1
unnamed: JP2.1 (A), R17.1
unnamed: R5.2, R6.1
unnamed: C4.1, U1.1 (BOOT)
unnamed: R4.2, R5.1, U1.4 (VSENSE)
unnamed: R9.1, U2.4 (CL)
unnamed: C8.1, U2.5 (DELAY)
unnamed: R11.2, U2.2 (DIAG_EN)
unnamed: R10.2, U2.1 (IN)
unnamed: R12.2, U2.3 (~FAULT)
unnamed: C5.1, U3.1 (OSCI), X1.1
unnamed: U3.2 (OSCO), X1.2
unnamed: R20.1, U4.8 (RS)
unnamed: C10.2, U5.9 (OSC1), X2.3 (OSC)
unnamed: R19.1, U5.19 (~RESET)

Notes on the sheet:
buck converter
aux headers
RPi EN
2A max
5V EN
PoE EN
500mA max
car input + protection
PoE high-side switch
usb-c power input header
CAN transceiver
status LEDs
termination jumper
PoE static injector
CAN controller
OR'd rail for 24V PoE
RTC + battery

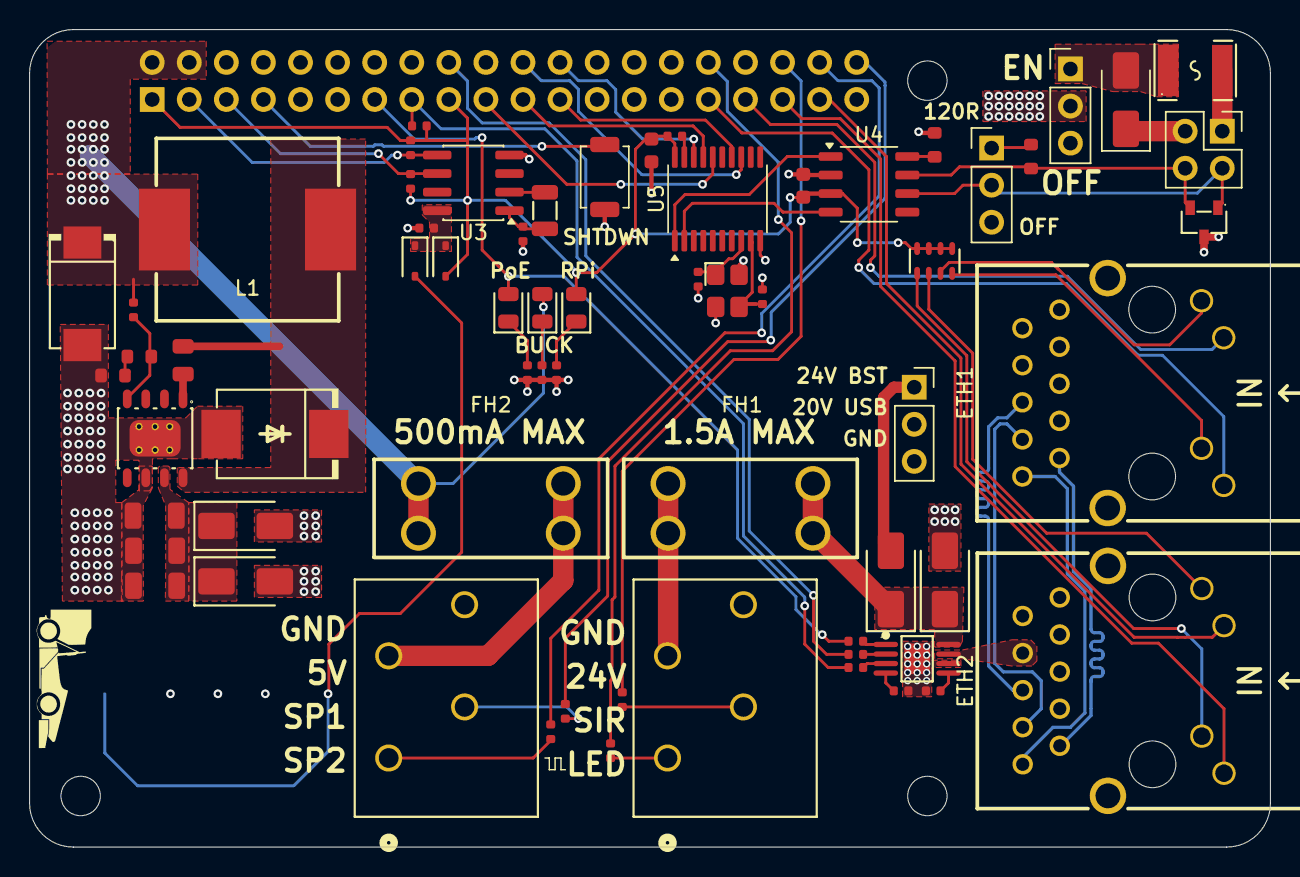
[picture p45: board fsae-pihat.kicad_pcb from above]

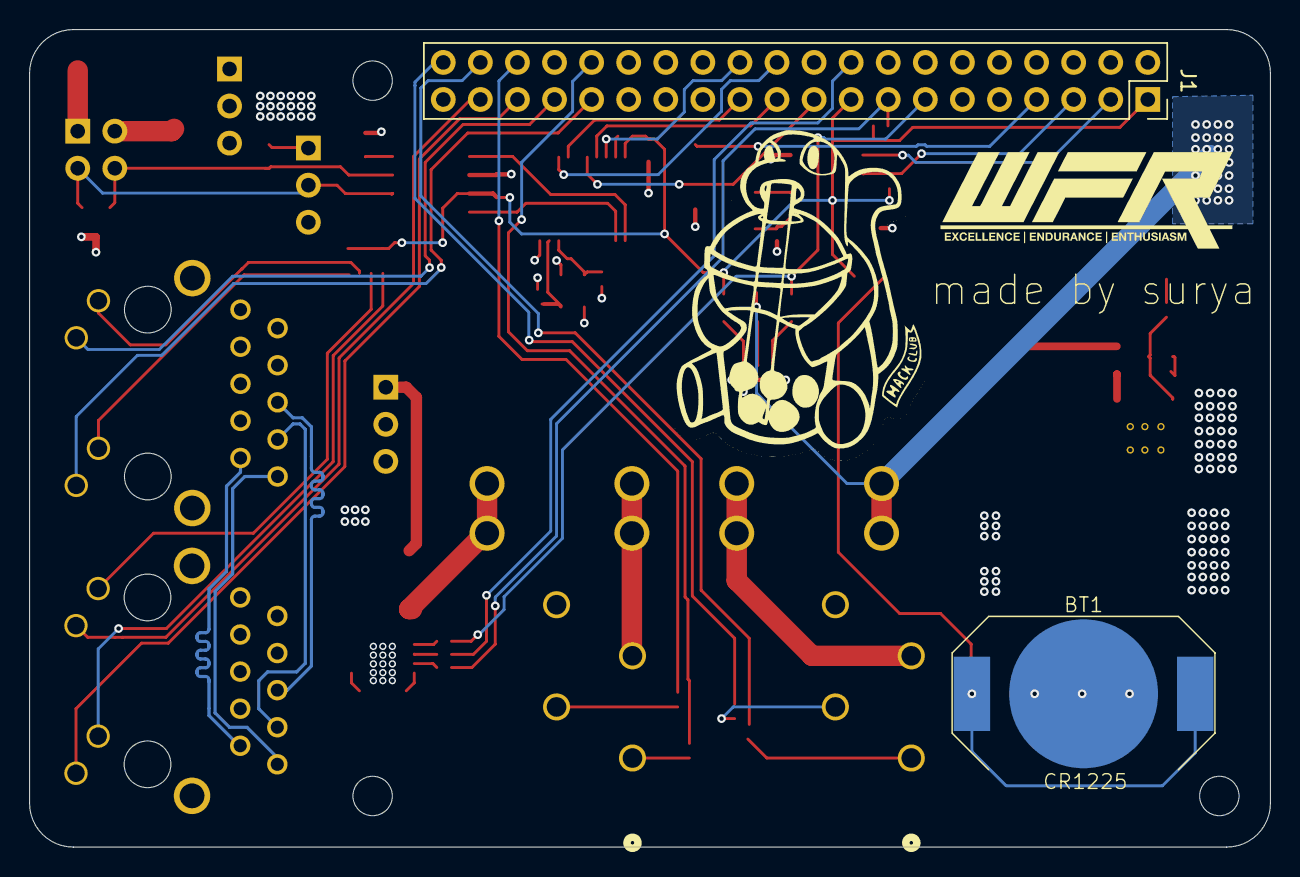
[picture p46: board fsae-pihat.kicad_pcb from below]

Board: 4 copper layers, 85.0 x 56.0 mm, 70 parts (2 on the bottom side), 69 nets.

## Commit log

2026-05-22 feat: readme, journal, pcb updates
    [bom.csv, designators.csv, fsae-pihat-usbmod.kicad_pcb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]
2026-05-23 feat: documentation and assembly
    [bom-digikeyca.csv, bom-lcsc.csv, bom-pihat.csv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]
2026-05-23 fix: assembly
2026-05-27 feat: pcb art and updated design
    [bom-pihat.csv, bom.csv, designators.csv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]
2026-05-28 fix: missed hat pullup; feat: new pd module
    [bom-pihat.csv, bom.csv, designators.csv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]
2026-05-28 fix: usb module fp + pcb
    [fsae-pihat-usbmod.kicad_pcb, fsae-pihat-usbmod.kicad_sch]
